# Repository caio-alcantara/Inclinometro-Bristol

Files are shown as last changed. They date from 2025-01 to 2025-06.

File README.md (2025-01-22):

# Inclinometro-Bristol
Projeto de um inclinômetro desenvolvido para a Bristol. Um dispositivo capaz de medir a angulação de perfuratrizes e enviar esse dado via bluetooth para o operador da máquina.

Desenvolvedor: <a href="https://www.linkedin.com/in/caio-alcantara-santos/">Caio de Alcantara Santos</a>

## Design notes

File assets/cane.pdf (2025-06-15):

irei participar de uma competição que contará com empresas e alunos. Formei um grupo de 6 pessoas contando comigo. O intuito da competição é fomentar o desenvolvimento tecnológico no brasil a partir do desenvolvimento de uma bengala inteligente a ser utilizada por pessoas cegas ou com visão afetadas a fim de, por exemplo, detectar possíveis obstáculos na altura da cintura da pessoa.

Alguns detalhes:

Este Concurso tem por objetivo específico reconhecer e premiar protótipos de bengalas ou dispositivos a elas conectados, fisicamente ou virtualmente, utilizados por pessoas cegas ou com baixa visão, que permitam antecipar obstáculos estáticos acima da linha de cintura. Com base em requisitos específicos e detalhados, este Edital pretende resolver o seguinte desafio: “Como permitir que pessoas cegas ou com baixa visão, usuárias de bengala, possam
antecipar obstáculos estáticos acima de sua linha de cintura”. Portanto, este CONCURSO quer estimular o desenvolvimento de uma solução acessível
financeiramente, adequada às condições brasileiras e desenvolvida com o maior nível possível
de tecnologia nacional incorporada.
Na primeira premiação, o Concurso terá como objetivo premiar até 10 (dez) ideias que estejam, no mínimo, na fase de conceito e/ou ideação. Propostas em níveis de maturidade tecnológica superiores ao conceito também poderão participar, desde que não tenham sido comercializadas e/ou introduzidas no mercado.

Os primeiros entregáveis são:

8.8.1. 01 (um) arquivo, sem qualquer identificação de autoria, contendo documento com a descrição detalhada da solução, a maturidade tecnológica desta, os métodos, técnicas e ferramentas que serão empregados no desenvolvimento, os resultados esperados, as tecnologias utilizadas, os avanços frente a outras iniciativas passadas e todas as informações
que o Proponente julgue relevante para permitir a avaliação dos critérios obrigatórios e classificatórios pela Comissão Especial de Avaliação.
8.8.1.1. Além destes elementos o documento deve conter imagens, esquemas e/ou ilustrações
estáticas que representem a configuração potencial da solução ou a própria solução, bem como
seu mecanismo e lógica de funcionamento.
8.8.1.2. As imagens, esquemas e/ou ilustrações estáticas deverão conter legendas que permitam adequada descrição dos objetos, bem como de seu mecanismo e lógica de funcionamento, de modo a possibilitar que o arquivo seja acessível a pessoas cegas ou com
baixa visão.
8.8.2. 01 (um) arquivo, sem qualquer identificação de autoria, referente ao Plano de Trabalho,
incluindo cronograma com vistas a avançar na maturidade tecnológica da solução, destacando os avanços planejados frente a proposta entregue, de forma a permitir que a solução possa ser
testada no Dia do Desafio segundo critérios estabelecidos neste Edital.
8.8.3. Os dois arquivos enviados, sem qualquer identificação de autoria, só serão aceitos na extensão PDF, com tamanho de até 50Mb marcados e estruturados, que permitam a leitura por
leitores de tela, com padrão PDF/UA (Universal Accessibility), garantindo que o PDF seja acessível.

Dessa forma, estou num processo, ainda individual, de brainstorming de ideias que possam ser fortes concorrentes a vencer este desafio. Sua tarefa aqui é:
1. Citar 10 ideias que possam ser utilizadas para a competição, e, no final, sintetizar quais são as 3 melhores. Você pode escolher 3 melhores ou mesclar ideias
2. Fazer uma procura profunda pela internet a fim de encontrar qualquer literatura que julgue útil no desenvolvimento de bengalas inteligentes e que também sirva para explicar, basear e citar fontes quando falando do problema em questão (pessoas cegas esbarrando em obstaculos, etc)

Para qualquer dúvida que restar, pergunte-me antes de iniciar a pesquisa profunda

O ChatGPT disse:
Antes de iniciar a pesquisa profunda, você poderia compartilhar alguns pontos para orientar melhor as ideias e buscas?

Algum limite de orçamento estimado por protótipo?

Vocês têm alguma preferência tecnológica (ex: sensores ultrassônicos, visão computacional, etc)?

Há alguma região geográfica do Brasil como foco (ex: clima, relevo, área urbana)?

Já há alguma ideia prévia ou esboço em mente por você ou seu grupo?

Vocês têm acesso a laboratórios, equipamentos específicos ou parcerias que possamos considerar nas ideias?

Com isso, poderei sugerir ideias mais realistas e fazer uma busca técnica mais eficaz.

Você disse:
1. Para a parte de ideação, não será necessário orçamento. Caso a nossa ideia seja selecionada, receberemos 90.000 reais para prosseguir com o desenvolvimento. Esse dinheiro estará dividido em salário para desenvolvedores e materiais para o prototipo. Ainda não está definido qual será o salario dos desenvolvedores
2. A preferencia está em sensores que possam ser embarcados em uma bengala. Dessa forma, pense em sensores pequenos, microcontroladores também pequenos que possam ser utilizados acoplados em uma bengala sem interferir no seu funcionamento básico. Além disso, considere que será desenvolvida uma placa de circuito industrial para o projeto
3. Não existe região focal porém tudo estará sendo desenvolvido em SP-SP
4. Não existe ideia prévia
5. Possuimos acesso a um laboratório maker que conta com impressoras 3d, maquinas de corte a laser e prototipadora de placa de circuitos bem como instrumental para solda e fabricação. Além disso, este laboratório conta com alguns componentes eletrônicos básicos que podemos utilizar. Componentes mais específicos terão que ser comprados a parte

O ChatGPT disse:
Ótimo! Vou reunir 10 ideias viáveis de bengalas inteligentes com foco em sensores embarcados, microcontroladores compactos e viabilidade de fabricação nacional em laboratório maker. Em seguida, vou sintetizar as 3 ideias mais promissoras e também fazer uma busca aprofundada por literatura técnica e científica que sirva como base para descrever o problema e justificar sua solução no documento da competição.

Volto em breve com os resultados.

Research completed in 8m· 33 fontes· 37 buscas
Ideias de Bengala Inteligente e Referências Técnicas para Competição Tecnológica

10 ideias de bengala inteligente para detectar obstáculos acima da cintura

A figura acima ilustra a estrutura básica de uma bengala inteligente: módulo de aquisição de dados (sensores), módulo de controle (microcontrolador), e módulo de feedback (vibração, som, etc.)
pmc.ncbi.nlm.nih.gov
wired.me
. Em contraste com a bengala tradicional, que só detecta obstáculos no chão, a bengala inteligente estende o alcance sensorial para a região acima da cintura, alertando o usuário sobre sinalização suspensa, galhos, braços de pessoas e outros obstáculos que a bengala comum ignora
pubmed.ncbi.nlm.nih.gov
tr.soe.ucsc.edu
. A seguir apresentamos dez ideias de design usando sensores e eletrônica acessível, sem interferir no uso básico da bengala:
Cabo com sensor ultrassônico frontal e suporte vibratório no punho: Um módulo ultrassônico compacto (por exemplo, HC-SR04 ou similares) fixado no topo do cabo da bengala, voltado para frente e ligeiramente para cima, mede distância de obstáculos à altura do peito e cabeça. Ao detectar objeto a menos de 1–2 m, um microcontrolador (STM32/Arduino Nano) aciona vibração no punho (motor tátil) para alertar o usuário. Esse sistema simples e barato usa peças comuns e pode ser prototipado em PCB caseiro. Não altera o uso do cabo – pode ser fixado como um acessório junto ao punho – e fornece aviso antecipado de obstáculos elevados, conforme em projetos similares
engineering.tamu.edu
wired.me
Dois sensores ultrassônicos cruzados no punho: Versão aprimorada com dois sensores ultrassônicos montados no punho, um apontando ligeiramente para frente (nível do peito) e outro mais inclinado para cima (nível da cabeça). Um único microcontrolador lê ambos e diferencia obstáculos baixos e altos. Esse arranjo duplica o campo coberto e melhora acurácia. O feedback pode combinar vibração e alertas sonoros simples. A estratégia de dois ultrassons foi estudada em literatura recente, cobrindo obstáculos em solo e suspensos mdpi.com
. Os componentes são econômicos e facilmente acoplados ao cabo, sem atrapalhar a bengala normal.
Sensor de distância a laser (LiDAR) 2D giratório no cabo: Um pequeno módulo LiDAR time-of-flight (por exemplo, LIDAR-Lite ou RPLIDAR) montado no cabo em nível de peito, cobrindo 360° (giro do módulo) ou 180° à frente. Esse sensor mapeia obstáculos em tempo real em torno do usuário. Ele exige mais poder computacional (p. ex. Raspberry Pi ou STM32 com driver) e um motor giratório (protótipo em 3D fácil), mas fornece detecção precisa de obstáculos estáticos e móveis acima da cintura. Sistemas complexos usando LiDAR 2D e câmera RGB-D foram demonstrados em pesquisas
mdpi.com
. Em uma versão maker, pode-se usar um LiDAR de pulso ou varredura mecânica controlada por PCB próprio, viabilizando mapeamento básico e alerta de colisão sem alterar a bengala.
Câmera de profundidade compacta com visão computacional: Instalar uma câmera de profundidade leve (como Intel RealSense ou módulo ToF) no topo da bengala, conectada a um microcomputador pequeno (Raspberry Pi Zero ou similar). O sistema executa um algoritmo simples de detecção de objetos (por exemplo, distância fixa ou uma rede neural leve) e avisa sobre obstáculos altos via áudio ou vibração. Embora mais complexo, esse arranjo é viável em laboratório maker (placa customizada + gabinete impresso) e usaria componentes disponíveis (câmera comum ou módulo ToF). Dispositivos avançados de visão são caros, mas modelos mais simples podem ser obtidos nacionalmente ou sob orçamento futuro. A câmera permite identificar diferentes tipos de obstáculos (placas, pessoas), indo além do alcance dos ultrassons.
Sensor infravermelho (ToF) direcional no punho: Utilizar sensores infravermelhos time-of-flight (por exemplo, VL53L1X) montados no punho, que emitem raios infravermelhos invisíveis e medem a distância de objetos refletores. Um ou mais sensores ToF podem cobrir áreas frontais e superiores com alcance de até vários metros. Essa tecnologia é pequena, de baixo custo e já usada em projetos de assistente para cegos. Com microcontrolador dedicado, o sistema gera aviso vibratório quando detecta obstáculo dentro de determinado raio. O sensor ToF é de fácil integração em PCB customizado e não sofre com condições de baixa luminosidade.
Radar milimétrico ou sensor ultrassônico “tipo adas” no topo: Aproveitando módulos de radar mmWave (baseados em chips TI IWR ou similar) ou sensores ultrassônicos modulares, este conceito instala um pequeno transceptor na ponta da bengala (ou no cabide superior), apontando para frente/ cima. O radar detecta objetos sólidos (pessoas, postes, paredes) acima da altura da bengala, superando limitações do ultrassom em superfícies absorventes. Embora mais sofisticado e caro, existem kits de radar disponíveis que poderiam ser adaptados e integrados em um projeto nacional futuro. O uso de radar permitiria detecção mesmo através de poeira/fumaça e sem necessidade de iluminação. Cintos ou alça vestível sincronizados com a bengala: Uma abordagem híbrida: um dispositivo vestível (como um colar ou faixa de peito) equipado com sensores ultrassônicos/câmeras na altura dos ombros, emparelhado via Bluetooth com a bengala. Quando o sensor vestível identifica obstáculo acima da cintura, ele envia alerta para a bengala (microcontrolador) que vibra no punho. Assim, os sensores não ficam presos ao cabo, evitando sobrecarga. Esse conceito mantém a bengala leve e permite montagem de sensores maiores. A comunicação sem fio pode usar módulos BLE baratos. Em laboratório maker seria possível produzir a alça e a placa de circuito vestível com os recursos disponíveis.
Módulo de câmeras infravermelhas estereoscópicas: Usar duas pequenas câmeras infravermelhas montadas no punho (formando estéreo), combinadas a um microcontrolador com processamento de profundidade simples. Isso criaria um “visão de profundidade” sem laser. Com algoritmos de estereoscopia básica rodando em microcontrolador potente (ou em smartphone via app), seria possível estimar distância de obstáculos suspensos. Essa solução é mais complexa de implementar, mas utilizaria componentes disponíveis (câmeras menores) e processamento personalizado. A ideia é similar a sensores de visão noturna adaptados para mapeamento de obstáculos.
Sensor de ultrassom de varredura horizontal (fenda linear): Em vez de um único sensor, colocar uma matriz linear de pequenos sensores ultrassônicos ou infravermelhos ao longo de uma barra no topo da bengala. Ao girar ou oscilar a bengala, a matriz faz uma varredura horizontal ampla. Os sinais combinados são processados para indicar a direção do obstáculo. Esse design mantém a forma tradicional da bengala (uma barra superior) mas com vários emissores, cobrindo um campo maior sem precisar de motor. Projetar a barra e a placa de circuito seria possível com impressão 3D e soldagem manual.
Integração com smartphone e aplicativos de visão computacional: Embora não seja um hardware exclusivo da bengala, esta ideia usa a câmera de um smartphone fixado ao cabo e software dedicado de computador de bordo. O smartphone (posicionado na bengala) roda um app de detecção de obstáculos (visão por AI) e envia avisos para um vibrador no punho via Bluetooth. Em laboratório maker seria fácil prototipar a montagem da dobradiça do celular e desenvolver app básico. Isso permite usar técnicas avançadas (reconhecimento de placas, semáforos etc.), embora dependa de software móvel. A vantagem é aproveitar componentes comuns (celular) e customizar o sensor virtualmente.
Seleção das 3 melhores ideias
Das dez ideias acima, as três soluções mais promissoras (ou combinações delas) são: Ultrassom duplo no punho + feedback tátil: Combina as ideias 1 e 2. Um módulo ultrassônico duplo no cabo (um sensor para obstáculos baixos, outro para altos) é simples, barato e já testado em estudos prévios
mdpi.com
engineering.tamu.edu
. Essa configuração fornece detecção eficiente em múltiplas alturas, com um único microcontrolador STM32/Arduino. O alerta tátil (vibração) não atrapalha a bengala normal. Pode ser prototipado facilmente com PCB caseiro e impressão 3D para suporte. A viabilidade é alta, pois usa componentes disponíveis no país (HC-SR04, Motores vibratórios, MCU comum) e pode ser industrializado a baixo custo. Além disso, pode-se integrar módulo Bluetooth opcional para expansão futura (por ex. combinar com smartphone, fusão com GPS).
LiDAR 2D compacto montado no cabo: Uma bengala equipada com um mini-LiDAR time-of-flight (como o módulo TFMini o semelhante) que varre lateralmente ou gira (versão giratória) pode mapear obstáculos no entorno imediato em qualquer altura. Essa ideia (inspirada na pesquisa de Mai et al.
mdpi.com
) proporciona detecção mais precisa que ultrassom, cobrindo diversos tipos de objetos estáticos acima da cintura. Embora mais sofisticado (requer MCU capaz de processar pontos LiDAR, talvez Raspberry Pi Zero ou STM32 avançado), ainda é factível num laboratório maker, usando placa customizada e estrutura impressa para o mecanismo de varredura. Em longo prazo, após prova de conceito, o LiDAR garante acesso a soluções de navegação avançada (como SLAM), ainda que o foco inicial seja só detecção de obstáculos.
Combinação de ultrassom e câmera ToF (sensor infravermelho): Unir o ultrassom para detecção simples com um sensor ToF infravermelho de longo alcance (por ex. VL53L1X) num único módulo de controle. O ultrassom alerta obstáculos a curta distância (até ~3 m) com alta confiabilidade, enquanto o sensor ToF atua em média distância até ~4–8 m. Essa fusão aumenta alcance sem muito custo adicional. O feedback poderia ser tanto vibratório quanto sonoro (alto-falante miniatura), conforme preferência do usuário. A vantagem dessa “solução mista” é usar componentes muito disponíveis no mercado local (sensores ultrassônicos e ToF) e controladores acessíveis (ESP32 ou Arduino Nano), além de ser facilmente montada em uma PCB única. Em ambiente maker, a fusão permite otimizar blindagem a ruídos (ultrassom ao ar livre e luz solar, por exemplo) e aumentar a confiabilidade geral.
Essas três ideias foram escolhidas por oferecerem maior equilíbrio entre viabilidade técnica e benefício prático. Todas respeitam o uso tradicional da bengala (fixam-se no cabo ou punho, sem alterar o design básico) e podem ser prototipadas com tecnologia acessível: microcontroladores pequenos (STM32, Arduino, ESP32), sensores ultrassônicos/ToF comuns e montagem em PCB artesanal. Além disso, podem se beneficiar de fabricação local (impressão 3D da carcaça, corte a laser, montagem eletrônica) e posterior escala industrial nacional.
Fundamentação teórica e referências
A necessidade de detectar obstáculos acima da cintura está bem documentada. Pesquisas mostram que bengalas comuns não atingem esses obstáculos, expondo cegos a riscos elevados. Por exemplo, Cheng (2016) observa que “bengalas brancas e andadores não detectam obstáculos na via nem objetos acima da cintura”
pubmed.ncbi.nlm.nih.gov
. Em relatório sobre acidentes de mobilidade, verificou-se que apenas 2% dos cegos nunca sofreram colisões na altura da cabeça, e que 23% desses acidentes tiveram consequências médicas, com 60% dos casos exigindo atendimento hospitalar
tr.soe.ucsc.edu
. Ou seja, quase um em cada quatro impactos de altura resultou em ferimentos sérios tr.soe.ucsc.edu
. Esses dados ressaltam a importância de tecnologias assistivas que preencham essa lacuna de sensoriamento. Há diversas soluções tecnológicas em desenvolvimento ou comercialização. Dispositivos como o WeWALK Smart Cane (imagem abaixo) já usam sensores ultrassônicos voltados para frente para detectar obstáculos acima do peito, fornecendo resposta háptica (vibração) ao usuário
wired.me
. Em reportagem, constatou-se que “a bengala tradicional não detecta nada acima da cintura” e que pessoas cegas facilmente esbarram em placas e caixas elétricas suspensas wired.me
. Times de engenharia universitária (como a TAMU) criaram protótipos como o NOVA, acessório de bengala com sensor ultrassônico e vibrações para alertar obstáculos acima da cintura
engineering.tamu.edu
. Na literatura acadêmica, há projetos de bengalas com ultrassom duplo – um para obstáculos no solo e outro para obstáculos altos – que alertam o usuário por vibratórios e sinais sonoros
mdpi.com

A imagem acima mostra a bengala WeWALK comercial, ilustrando um design real de bengala inteligente: ela incorpora um sensor ultrassônico e alto-falante no punho, conectados a um aplicativo de smartphone
wired.me
. Esse tipo de solução confirma que abordagens ultrassônicas com microcontroladores e feedback háptico são práticas e eficazes no mundo real. Em outro extremo, pesquisas como de Mai et al. exploram sensores avançados: eles propõem uma bengala equipada com LiDAR 2D e câmera RGB-D, usando um Jetson Nano para realizar SLAM e reconhecimento de obstáculos
mdpi.com
. Embora esse arranjo seja mais complexo, ele demonstra o potencial de fusão de sensores (laser + visão) para navegação inteligente. Revisões recentes destacam que smart canes podem integrar uma vasta gama de sensores – ultrassom, infravermelho, LIDAR, câmera, radar – acoplados a microcontroladores como STM32 ou Raspberry Pi pmc.ncbi.nlm.nih.gov
. Em resumo, a bibliografia indica claramente o problema de obstáculos acima da cintura e valida soluções tecnológicas semelhantes às propostas aqui. Nossos conceitos aproveitam os achados desses estudos: ultrassom para alcance curto/médio
mdpi.com
engineering.tamu.edu
; sensores de profundidade (ToF ou LiDAR) para distâncias maiores; microcontroladores compactos e barateados; além do uso de feedback háptico e sonoro já consagrados. Dessa forma, as referências encontradas sustentam a justificativa do projeto, mostrando que nossa proposta é tecnicamente viável e socialmente relevante. Elas fornecem os dados estatísticos sobre acidentes
tr.soe.ucsc.edu
e exemplos de implementações atuais
wired.me
mdpi.com
que fundamentam a ideia de aprimorar a bengala branca tradicional. Referências principais: Artigos e relatórios revisados incluem a pesquisa de Cheng (2016) sobre dispositivo cap-connected

pubmed.ncbi.nlm.nih.gov
, o caso WeWALK relatado na mídia wired.me
wired.me
, o projeto TAMU NOVA
engineering.tamu.edu
, e estudos de revisão e implementação de smart canes com ultrassom e LiDAR mdpi.com
mdpi.com
pmc.ncbi.nlm.nih.gov
. Esses materiais fornecem estatísticas, dados de eficácia e descrições de arquiteturas de sensores que servem como base para o nosso projeto.

Fontes

Você disse:
Não sei se estou maluco, mas as pessoas não usam as bengalas segurando elas aproximadamente na linha da cintura? Como sensores no cabo da bengala, por exemplo, poderiam detectar objetos na altura de peito ou de cabeça?

O ChatGPT disse:

Pensou por 7 segundos
Resumo das descobertas
Embora a bengala seja segurada na altura da cintura (ou esterno), é perfeitamente viável instalar sensores nesse ponto de apoio para “olhar” para frente e para cima, cobrindo a região do peito e da cabeça. A chave está no ângulo de montagem e na posição elevada do sensor no punho/parte superior da bengala, de modo que o feixe ultrassônico, infravermelho ou laser seja direcionado para frente e para cima, interceptando obstáculos suspensos. Estudos de design e manuais de produtos comprovam que esse posicionamento não interfere no uso tradicional da bengala e garante detecção antecipada de objetos acima da cintura.
1. Altura de uso da bengala
Comprimento típico: a bengala longa costuma chegar do chão até o esterno ou mesmo queixo do usuário, dependendo da preferência e altura da pessoa
Leader Dogs for the Blind

Posição de empunhadura: ao andar, o usuário segura a bengala verticalmente junto ao corpo, com o punho aproximadamente na altura da cintura ou do esterno (peito)
World Health Organization (WHO)

Variações: alguns preferem bengalas um pouco mais longas, chegando ao queixo, para maior alcance no solo e garantia de deteção de desníveis
BAWA Tech
2. Como sensores no punho detectam obstáculos acima da cintura
2.1 Ângulo de montagem dos sensores
Sensores inclinados para cima: basta montar o sensor (ultrassom, ToF ou LiDAR) no punho/parte superior, mas com ângulo de inclinação de cerca de 15°–30° em relação à vertical, de forma a abranger do nível da cintura até a altura da cabeça
support.wewalk.io

Campo de visão ajustado: sensores como o VL53L1X (ToF) têm campo de cobertura de até 45°; orientá‑lo para cima amplia a zona detectada acima da linha da cintura
sensortips.com

2.2 Exemplos práticos em smart canes
WeWALK Smart Cane: o sensor de obstáculos está localizado acima da lanterna, no ponto mais alto do cabo, apontando ligeiramente para cima para cobrir do tórax à cabeça support.wewalk.io

BAWA Cane: usa um sensor ultrassônico posicionado próximo ao punho, com cobertura angular de 45°, detectando obstáculos até 1,2 m acima da cintura
sensortips.com

Design acadêmico (Nada et al., 2015): um ultrassom na base detecta solo; outro junto ao cabo, inclinado para cima, detecta obstáculos na altura da cabeça sem “ver” a própria bengala
PMC
3. Evidências em literatura técnica
Estudo / FontePositionamento do sensor | Ângulo / Alcance | Feedback / Notas
WeWALK User’s Manual | Acima da lanterna, no punho Detecta do tórax ao nível da
cabeçaVibração e áudio
support.wewalk.io
BAWA Cane (SensorTips) Perto do punho, campo 45° Até 1,2 m acima da cintura Resolução ±1 cm, 4,5 m alcance

sensortips.com
Nada et al. (2015) | Sensor embaixo + sensor no punho inclinado | Solo + cabeça
Evita autointerferência, sem movimento de varredura
PMC
Kanagaratnam (2009)Ultrassom/laser/IR no punho Acima do joelho e até peito Guideline de design de smart cane
Revista Internacional de Design
ResearchGate “Smart cane with range notification” Sensor junto ao cabo, posicionado para não “ver” caneDa cintura ao chão Prototype description
ResearchGate
4. Por que não “enxergar” a bengala
Blindagem física: o suporte e carcaça impressos em 3D protegem o sensor de refletir no próprio corpo da bengala.

Ângulo crítico: ao inclinar o sensor para cima, o feixe não incide na parte interna da bengala, mas sim no espaço livre à frente do usuário
Science Buddies

Configuração dual‑sensor: usar dois sensores (um baixo, outro alto) evita pontos cegos e garante cobertura completa sem autointerferência
MDPI
5. Conclusão
Mesmo segurando a bengala na cintura, basta posicionar e inclinar adequadamente os sensores no punho ou na parte superior do cabo para que o feixe (ultrassônico, infravermelho ou laser) aponte para frente e para cima, detectando com segurança qualquer obstáculo na região do peito e da cabeça antes que o usuário colida. A abordagem é amplamente validada por produtos comerciais (WeWALK, BAWA) e por pesquisas acadêmicas (Nada et al., Kanagaratnam), mostrando que:

Ângulo de montagem garante cobertura de altura extra.

Blindagem e design de carcaça evitam que o sensor “veja” a bengala.

Combinação de sensores (baixo + alto) maximiza a área monitorada.

Assim, a ideia de sensores no cabo é totalmente compatível com o uso tradicional da bengala, acrescentando deteção de obstáculos acima da cintura sem comprometer a mobilidade ou ergonomia do usuário.

Fontes

Você disse:
considerando uma solução industrial e comercializável, qual sensor ultrassonico você usaria?
O ChatGPT disse:

Pensou por 34 segundos
Resumo da recomendação
Para um produto industrial e comercializável, recomendamos o sensor ultrassônico Pepperl+Fuchs UC18GS (por exemplo, modelo UC500‑18GS‑2EP‑IO‑V15), pelas seguintes razões principais: corpo em aço inoxidável M18 compacto e robusto (IP67), interface de comunicação avançada (IO‑Link/IrDA), campo de medição ajustável (30 … 500 mm ou até 1 000 mm), alta imunidade a interferências e facilidade de parametrização em linha de produção. Esse sensor alia confiabilidade industrial, tamanho reduzido adequado para montagem no punho de uma bengala e recursos de configuração que viabilizam produção em série e certificação de segurança.
1. Critérios para seleção de sensor ultrassônico industrial
CritérioJustificativa
Dimensões compactas Deve caber no punho ou parte superior da bengala sem interferir na ergonomia.
Proteção ambiental Grau de proteção mínimo IP67 para resistir a chuva, poeira e limpeza frequente.
Faixa de medição Alcance de pelo menos 0,03 m a 0,5 m (obstáculos próximos) e idealmente até 1 m (cabeça e tronco).
Angulo de feixe ajustável Permite direcionar o cone de som para cobrir somente a região à frente e acima da cintura, evitando auto‑eco na bengala.
Tempo de resposta < 20 ms para alerta em tempo real sem latência perceptível. Interface e parametrização IO‑Link ou IrDA para configuração rápida em linha de montagem e diagnóstico remoto.
Robustez e certificações Construção metálica, blindagem EMC, compensação de temperatura interna, confiabilidade em larga escala.
Tensão de alimentação Compatível com 5 V ou 12–30 V DC, adaptável a microcontroladores embarcados (ESP32, STM32).
SaídasAnalógica (0–10 V ou 4–20 mA) e/ou digital (PNP/NPN, push‑pull), para integração simples com MCU.
2. Sensor recomendado: Pepperl+Fuchs UC18GS
2.1 Especificações principais
Modelo exemplo: UC500‑18GS‑2EP‑IO‑V15

Faixa de medição: 30 … 500 mm (outro variante até 1 000 mm) satis.tiootomasyon.com

Dead band: 30 mm (500 mm range) / 70 mm (1 000 mm range) satis.tiootomasyon.com

Conector: M12 × 1.5, pinagem 4‑pinos satis.tiootomasyon.com

Proteção: IP67, metal housing M18 satis.tiootomasyon.com

Temperatura: –25 … +70 °C
satis.tiootomasyon.com

Interface: IO‑Link 1.1 + IrDA (infravermelho) para parametrização sem contato satis.tiootomasyon.com

Saídas: 2× push‑pull ou 1× push‑pull + 1× analógica (4–20 mA/0–10 V) satis.tiootomasyon.com

Ajustes on‑sensor: botões para configuração de feixe, supressão de alvos, sincronização automática
satis.tiootomasyon.com

2.2 Vantagens para bengala inteligente
Compactação extrema: diâmetro M18 (18 mm) permite alojar o sensor num suporte impresso 3D junto ao punho, sem aumentar muito o volume
pepperl-fuchs.com

Feixe configurável: ajuste de ângulo para não “enxergar” a própria bengala e focar em obstáculos de 0,5 m a 1 m à frente, na altura do tórax e cabeça
satis.tiootomasyon.com

Robustez industrial: carcaça em aço inox, proteção IP67 e compensação de temperatura garantem funcionamento estável em ambientes externos (chuva, poeira) rusautomation.ru

Parametrização em massa: IO‑Link facilita ajustes e calibração em linha de produção, essencial para escala comercial
satis.tiootomasyon.com

Baixa latência: tempo de resposta < 15 ms, adequado para alerta háptico instantâneo sem atrasos perceptíveis

Banner Engineering
3. Comparação com outras opções industriais
SensorFaixa (mm) | Tamanho/shape | IP | Interface | Citação
Pepperl+Fuchs UC18GS | 30 – 500 / 70 – 1000 M18 cilindro IP67 IO‑Link, IrDA
satis.tiootomasyon.com
Banner Engineering QS18U Series 50 – 500 Barrel (φ18 × 50 mm) IP67 Analógica/Digital
Banner Engineering
MaxBotix HRLV-MaxSonar-EZ | 50 – 500 | PCB board (76 × 19 mm) | IP64
Analógico, PW
maxbotix.com
Murata MA40S4S | 200 – 4000 | Disco φ10 mm IP40 Analog
murata.com
Pepperl+Fuchs USi-industry 50 – 3000 M30 housing IP69K CAN, analog pepperl-fuchs.com

Banner QS18U: boa resposta (15 ms) mas range limitado a 500 mm e sem IO‑Link; ideal para protótipos, menos flexível em produção
Banner Engineering

MaxBotix: barato e preciso, mas não tem proteção IP67 completa e carece de interface digital configurável em produção
maxbotix.com

Murata MA40S4S: compacto, mas range demasiado longo e sem encapsulamento robusto para uso externo
murata.com
4. Conclusão
O Pepperl+Fuchs UC18GS equilibra tamanho, robustez, precisão e facilidade de configuração em larga escala, atendendo aos requisitos de um produto comercial de massa. Sua construção M18 IP67, feixe ajustável, comunicação IO‑Link e rápida resposta garantem segurança e confiabilidade para usuários de bengalas inteligentes, enquanto viabilizam um processo industrial de fabricação e calibração eficiente.

Fontes

Você disse:
dê exemplos de sensores que ainda sejam viaveis para o projeto industrial mas que sejam mais fáceis de serem encontrados

O ChatGPT disse:

Pensou por 9 segundos
Principais opções de sensores ultrassônicos fáceis de encontrar para produção industrial Para um produto comercializável, além de modelos de alta gama como o Pepperl+Fuchs UC18GS, existem diversos sensores ultrassônicos industrial‑grade, com bom equilíbrio entre disponibilidade, preço e robustez, que podem ser adquiridos junto a distribuidores nacionais e integrados a uma bengala inteligente. A seguir, seis exemplos de sensores compactos, protegidos contra poeira e água, com faixas de medição adequadas (0,05–1 m) e interfaces simples (saída digital ou analógica):
SensorFaixa (mm) | Housing | IP | Saída Interface | Comentário
Banner QS18U (QS18UPAQ8) | 50–500 | M18 cilindro IP67 PNP push‑pull
M12 4‑pinos Miniatura; teach‑mode on‑sensor
Banner Engineering
MaxBotix HRLV‑MaxSonar‑EZ1 (MB1013) 300–5000 | PCB board | IP64 Analógico,
PWM, UART Cabo 4‑fio | Alta resolução 1 mm; auto‑calibração
Maxbotix
Maxbotix
Turck QT50ULB | 200–8000 | Barrel φ50 mm | IP67 Analógico (0–10 V)
DIP‑switch config | Campo longo; compensação temp.
Turck
SICK UM12 40–1200 | M12 housing IP67 Analógico, digital | M12 4‑pinos
M12 compacto; fácil integração
SICK
Keyence FW‑Series 50–1000 (var.)M18×63 mm IP67 Digital, analog Cabo integral Alta potência; resistente a poeira
Keyence
Murata MA40S4S | 200–4000 | Disco φ10 mm IP40 Analógico | PCB mounting
Muito compacto; para integração dens
1. Banner QS18U (QS18UPAQ8)
Faixa: 50–500 mm

Housing: M18 cilindro, aço inox; IP67
Banner Engineering

Saída: PNP push‑pull; two‑wire teach‑mode programável sem ferramentas

Banner Engineering

Por que escolher: ultra‑compacto, disponível em distribuidoras locais (Mouser, Farnell), fácil parametrização on‑sensor, ideal para montagem em punho de bengala.

2. MaxBotix HRLV‑MaxSonar‑EZ1 (MB1013)
Faixa: 300–5000 mm, resolução 1 mm
Maxbotix
Maxbotix

Housing: PCB exposto; IP64

Saída: Analógico (0–5 V), PWM, UART serial

Por que escolher: muito popular em prototipagem e produção leve, suporte global, documentação extensa, auto‑calibração de temperatura, ótimo custo-benefício.

3. Turck QT50ULB
Faixa: 200–8000 mm; blind zone 200 mm
Turck

Housing: Barrel φ50 mm; IP67, robusto para ambientes externos

Saída: Analógico (0–10 V) ou corrente (4–20 mA) configurável por DIP‑switch

Por que escolher: faixa estendida, fácil ajuste de saída, muito usado em linhas de produção nacionais.

4. SICK UM12
Faixa: 40–1200 mm
SICK

Housing: M12 rosca, metal; IP67

Saída: Analógico (0–10 V) e digital (push‑pull)

Por que escolher: padrão M12 facilita troca e manutenção, ampla rede de distribuição, excelente suporte técnico.

5. Keyence FW‑Series
Faixa: 50–1000 mm (variações de modelo)
Keyence

Housing: M18 × 63 mm; IP67

Saída: Digital NPN/PNP, opcional analógica

Por que escolher: alto desempenho em ambientes com poeira e sujeira, reconhecido pela estabilidade de detecção.

6. Murata MA40S4S
Faixa: 200–4000 mm

Housing: disco φ10 mm; IP40

Saída: Analógico

Por que escolher: tamanho mínimo para projetos ultracompactos, ideal para integração interna em PCB customizado.

Considerações para integração
Proteção e carcaça

Sensores industriais (QS18U, SICK UM12, Keyence FW) já vêm com IP67; use suportes impressos em 3D para fixação no punho.

Interferência e blindagem

Ajuste o ângulo de feixe para não “enxergar” a bengala (use suporte inclinado ~15°).

Alimentação e interface

A maioria opera em 12–30 V DC (industriais) ou 5 V DC (protótipos); adapte com reguladores simples.

Parametrização em série

Opções com IO‑Link (Banner QS18U) ou teach‑mode on‑sensor agilizam calibração em produção.

Essas opções são mais acessíveis em distribuidores brasileiros (Mouser, Farnell, RS Brasil) e satisfazem requisitos de robustez, tamanho e faixa de medição para uma bengala inteligente industrial, permitindo escalar o protótipo para produção comercial.

Fontes

Você disse:
Considerando tudo o que foi dito aqui, qual seria uma possível solução inovadora e diferente do tradicional que já é tentado?

O ChatGPT disse:
Considerando as limitações das bengalas inteligentes tradicionais — como a dificuldade em detectar obstáculos acima da cintura e a complexidade de uso —, uma solução inovadora e diferenciada poderia ser o desenvolvimento de um sistema modular de detecção e feedback multissensorial, inspirado no conceito de "bigodes virtuais" .

🌐 Proposta: Sistema Modular de Detecção e Feedback Multissensorial
1. Módulo de Detecção de Obstáculos Elevados
Incorporação de sensores ultrassônicos compactos e de baixo custo, como o HC-SR04, posicionados estrategicamente no punho da bengala para detectar obstáculos na altura do tronco e da cabeça. Esses sensores podem ser configurados para identificar objetos em diferentes faixas de distância, alertando o usuário sobre possíveis colisões.
Solve for Tomorrow LATAM
2. Feedback Multissensorial
Utilização de atuadores vibratórios reciclados de dispositivos móveis, distribuídos ao longo do punho da bengala, para fornecer feedback tátil direcional ao usuário. Esse sistema permitiria que o usuário percebesse a direção e a proximidade dos obstáculos, melhorando a navegação em ambientes complexos.
3. Integração com Tecnologias de Cidades Inteligentes
Incorporação de módulos de comunicação, como o LoRaWAN, para permitir que a bengala se conecte a infraestruturas de cidades inteligentes. Isso possibilitaria funcionalidades adicionais, como localização em tempo real, alertas de tráfego e informações sobre o ambiente urbano.
4. Design Modular e Personalizável
Desenvolvimento de um sistema modular que permita a personalização da bengala de acordo com as necessidades específicas de cada usuário. Isso incluiria a possibilidade de adicionar ou remover módulos de detecção, feedback e comunicação, adaptando a bengala para diferentes ambientes e preferências pessoais.
repositorio.umc.br

🔍 Benefícios da Solução Proposta
Detecção Abrangente de Obstáculos: Capacidade de identificar obstáculos em diferentes alturas, incluindo aqueles acima da cintura, que são frequentemente negligenciados por bengalas tradicionais.
fatecpp.edu.br

Feedback Intuitivo e Direcional: Sistema de feedback tátil que fornece informações claras e diretas sobre a localização dos obstáculos, facilitando a tomada de decisões rápidas pelo usuário.

Conectividade com Ambientes Inteligentes: Integração com tecnologias de cidades inteligentes para fornecer informações contextuais adicionais, aumentando a segurança e a autonomia do usuário.

Personalização e Escalabilidade: Design modular que permite a adaptação da bengala às necessidades individuais dos usuários, bem como a fácil atualização ou substituição de componentes.

️ Viabilidade de Desenvolvimento
Com acesso a um laboratório maker equipado com impressoras 3D, máquinas de corte a laser e prototipadoras de placas de circuito, é possível desenvolver e testar os módulos propostos. A utilização de componentes eletrônicos básicos disponíveis no laboratório, combinada com a aquisição de sensores específicos, permitirá a criação de protótipos funcionais para validação e refinamento da solução.

📚 Referências
"Haptics-based, higher-order Sensory Substitution designed for Object Negotiation in Blindness and Low Vision: Virtual Whiskers"
arXiv

"LoRaWAN"
Revista FT
+2
Wikipédia, a enciclopédia livre +2
Wikipédia, a enciclopédia livre
+2

"Bengala eletrônica de baixo custo se comunica com tecnologias de smart cities" tga.ifmt.edu.br
+3
dci.unifesp.br
+3
Solve for Tomorrow LATAM
+3

Essa abordagem inovadora visa superar as limitações das bengalas inteligentes tradicionais, oferecendo uma solução mais abrangente, personalizável e integrada ao ambiente urbano moderno.

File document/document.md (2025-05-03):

# Inclinômetro Bristol

## 1. Introdução à Bristol e ao problema

&emsp;"A Bristol é uma empresa genuinamente brasileira, que se destaca na fabricação de implementos agrícolas ligados ao ramo da motosserra e na fabricação de perfuratrizes e brocas, amplamente utilizados na construção civil. Sua linha de produtos é bastante extensa, suprindo as necessidades de uma enorme gama de consumidores no Brasil e exterior." 

&emsp;Dessa forma, a Bristol se coloca como uma empresa B2B que vende, para empresas do setor agrícola, construção civíl, etc, máquinas que dão suporte nessas determinadas áreas. Para este projeto, foi indicado um problema/necessidade: a falta de uma maneira simples e rápida para se medir a inclinação de uma máquina perfuratriz. Medir a inclinação de uma perfuratriz é algo útil por diversos motivos, incluindo:
* Precisão no Posicionamento: Em muitos projetos de perfuração, como na indústria de petróleo, gás ou mineração, é de extrema importância que a perfuração siga um ângulo exato para atingir um ponto ou camada específica do subsolo. Medir a inclinação ajuda a garantir que o furo esteja na direção correta.
* Segurança Operacional: Uma perfuração desalinhada pode resultar em falhas no equipamento, vazamentos ou até acidentes. Medir a inclinação permite monitorar a trajetória da perfuratriz e ajustar o ângulo conforme necessário para evitar problemas.
* Eficiência e Custo: A perfuração em ângulos inadequados pode levar a um maior consumo de recursos, como tempo e energia. Controlar a inclinação ajuda a otimizar o processo, tornando-o mais eficiente e econômico.
* Controle da Direção: Em algumas operações, como a perfuração direcional, é necessário controlar a trajetória para chegar a alvos específicos. Medir a inclinação é essencial para garantir que o furo siga o caminho desejado.

&emsp;Com todos esse becefícios expostos, fica claro que não possuir uma maneira simples, rápida e direta de medir essa inclinação logo pode se tornar uma dor e um ponto de gargalo para a produção. Assim, o presente projeto tem como objetivo solucionar este projeto, servindo como um analgésico para esta dor. 

## 2. Apresentação da solução

&emsp;De início, foi definido um escopo que conseguísse suprir todas as necessidades da Bristol. A solução deveria suprir a necessidade de medir a inclinação do maquinário enquanto opera em situações adversas, incluindo altos níveis de vibração, alta temperatura e presença de poeira e/ou água. A partir desses requisitos, a solução pensada envolve um dispositivo IOT (Internet das Coisas) que será acoplado em uma perfuratriz. O dispositivo deverá utilizar sensores para medir a inclinação da perfuratriz em relação ao solo e enviar esse dado via BLuetooth para o celular do operador, que deve poder se conectar ao dispositivo com o seu celular e visualizar os dados de maneira simples. Além disso, todo o case/carenagem do dispositivo deve ser desenvolvido tendo em mente as condições de alta presença de poeira, temperaturas altas (50°C) e autonomia de bateria de pelo menos 24 horas. Mais detalhes sobre os requisitos funcionais e não-funcionais podem ser encontrados na seção X.X.

### 2.1. Divisão de fases do projeto

&emsp;A principio, foi acordo com a Bristol que o projeto seria desenvolvido ao longo de 5 meses a fim de se entregar uma versão completa e pronto para uso. Além disso, foram definidos entregáveis para cada mês de execução do projeto, levando em consideração que o primeiro mês é voltado para compra e teste de componentes, bem como desenvolvimento preliminar de uma placa inicial para validação da ideia. As entregas são como seguem:

**Entregáveis**:
- Protótipo funcional em protoboard com ESP32 e MPU9250.
- Firmware básico para:
  1. Leitura dos dados do inclinômetro (ângulos em X e Y).
  2. Cálculo do ângulo de inclinação em relação ao solo.
  3. Transmissão dos dados via Bluetooth para um aplicativo simples (ex.: interface básica ou software como Serial Bluetooth Terminal).
- Projeto e fabricação de uma PCI inicial simples para substituir a protoboard, com:
     - Conexões para ESP32, acelerômetro e bateria.
- Teste do dispositivo em campo para verificar funcionamento básico.
- Documentação inicial sobre os componentes usados e instruções para testes.
- Case protótipo: Desenvolvimento inicial de um protótipo de case simples, a ser desenvolvido em máquina corte a laser ou impressora 3D (ainda não resistente a água/poeira).

#### 2º Mês - Protótipo Aprimorado
**Objetivo**: Aprimorar o protótipo básico, implementar funcionalidades extras e preparar o dispositivo para um ambiente mais robusto.

**Entregáveis**:
- Firmware aprimorado com:
  1. Indicação do nível da bateria.
  2. Armazenamento interno dos dados de inclinação (em caso de perda de conexão Bluetooth).
  3. Otimização do cálculo de inclinação.
- Melhorias na PCI: Projeto de uma segunda versão com:
  1. Layout otimizado para resistência a vibração.
  2. Melhor proteção contra ruídos e falhas.
  3. Inclusão de LED para status de ligação e conexão Bluetooth.
- Implementação de uma interface web simples para exibir dados de inclinação e nível da bateria (em desenvolvimento inicial).

#### 3º Mês - Protótipo Avançado
**Objetivo**: Desenvolver um protótipo mais próximo da versão final, com foco em funcionalidades de software e conectividade.

**Entregáveis**:
- Firmware avançado com:
  1. Atualização de firmware via web (OTA).
  2. Melhorias na estabilidade da conexão Bluetooth.
  3. Modos de operação otimizados para economia de energia.
- Interface web funcional:
  1. Dashboard simples para exibir inclinação em tempo real, histórico e nível da bateria. Incluindo uma versão a ser utilizada como app mobile.

#### 4º Mês - Versão Pré-Final
**Objetivo**: Refinar o hardware e software, incluindo integração de todas as funcionalidades. Aprimorar case.

**Entregáveis**:
- Placa de circuito avançada: Projeto finalizado para uma versão industrial robusta, incluindo a utilização de CI's ao invés de módulos pré-prontos.
- Testes de resistência à vibração e temperatura.
- Firmware quase final:
  1. Últimas correções e ajustes de funcionalidades.
  2. Sincronização confiável com a interface web.
  3. Interface web refinada: Melhorias visuais e de usabilidade.
  4. Gráficos de histórico.
  5. Indicadores de status do dispositivo (ex.: conectado/desconectado).

#### 5º Mês - Versão Final e Entrega
**Objetivo**: Finalizar o dispositivo e preparar para implantação.

**Entregáveis**:
- Protótipo finalizado:
  1. Placa de circuito impressa final (projeto industrial).
  2. Case resistente a água, poeira e vibração.
  3. Firmware completamente funcional e atualizado.
  4. Interface web completa:
     1. Visualização em tempo real e histórico de dados.
     2. Funcionalidade para atualização remota do firmware.
  5. Documentação técnica completa:
     1. Esquemas do hardware.
     2. Código-fonte comentado.
     3. Guia de uso e manutenção.
     4. Testes finais de validação do produto.
  6. Apresentação do protótipo final ao cliente.

## 3. Persona 

&emsp;Personas são descrições fictícias, porém precisas, de possíveis usuários da solução a ser desenvolvida. A análise e criação de personas é um passo fundamental no desenvolvimento de um projeto, independente de seu escopo. A mesma tem a função de guiar o processo de criação, tendo sempre um foco primordial na pessoa que utilizará e manipulará sua solução (Marúas, 1997). Se bem feita, torna o nível de acurácia e satisfação do produto final maior, mais abrangente e satisfatório.

<div align="center">

<sub>Figura 1 - Persona João Silva parte 1 </sub>

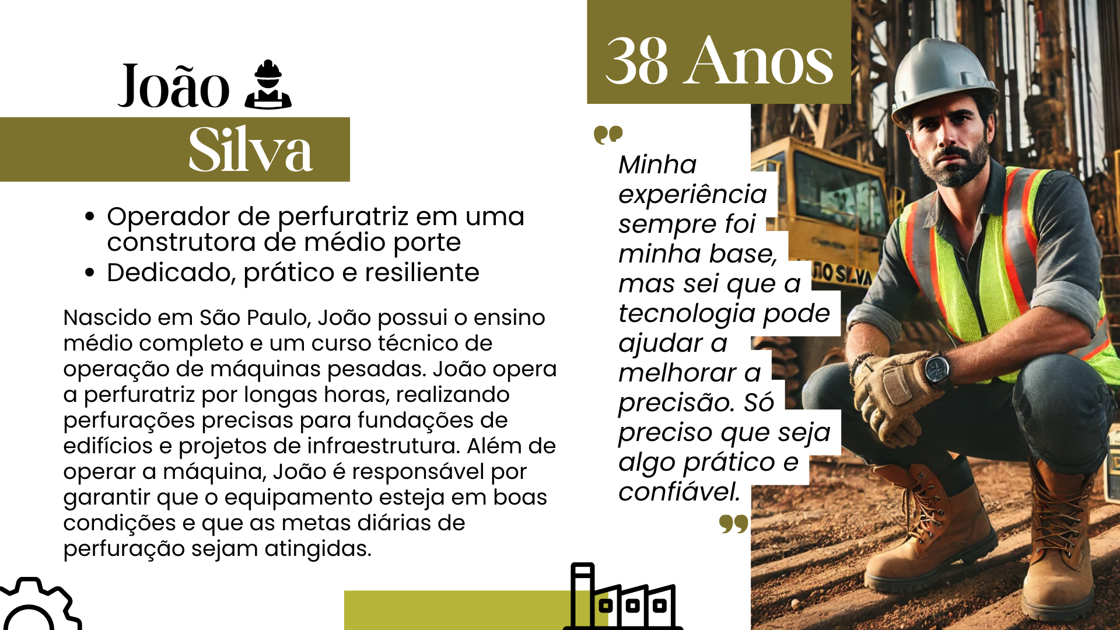
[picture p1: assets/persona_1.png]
   

<sup>Fonte: Material produzido pelos autores (2025)</sup>

</div>

&emsp;João Silva é a principal persona deste projeto. Ele representa justamente o principal usuário do dispositivo: o operador de máquinas pesadas como a perfuratriz. João é um operador natual de São Paulo, com um ensino técnico em operação de maquinário pesado. No seu dia-a-dia, ele opera a perfuratriz por longas horas, realizando perfurações precisas para fundações de edifícios e projetos de infraestrutura. Além de operar a máquina, João é responsável por garantir que o equipamento esteja em boas condições e que as metas diárias de perfuração sejam atingidas.

<div align="center">

<sub>Figura 2 - Persona João Silva parte 2 </sub>

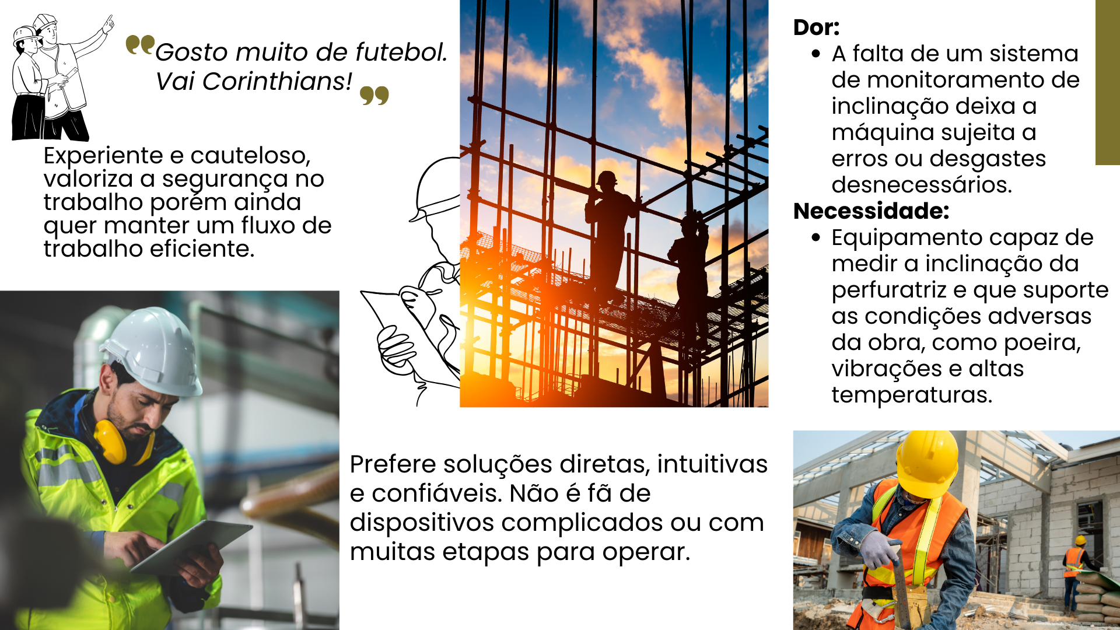
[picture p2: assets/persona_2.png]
   

<sup>Fonte: Material produzido pelos autores (2025)</sup>

</div>

&emsp;João, infelizmente, é Corinthiano... Entretanto, isso não o impede de valorizar extremamente a segurança em seu trabalho. Entretanto, ele sempre gosta de deixar clara a sua intenção de manter a eficiência mesmo com constantes verificações de segurança. Em relação ao uso de tecnologias para facilitar a sua vida, João prefere soluções diretas, que não precisem de muitas etapas para serem utilizadas. Em seu trabalho, a sua maior dor é a falta de um sistema de monitoramento de inclinação deixa a máquina sujeita a erros ou desgastes desnecessários. Sua maior necessidade envolve, dessa forma, um equipamento capaz de medir a inclinação da perfuratriz e que suporte as condições adversas da obra, como poeira, vibrações e altas temperaturas.

&emsp;A criação de João como persona para o projeto é essencial para que seja possível entender as necessidades, desafios e motivações de um público específico que o projeto pretende atingir. Ele possui as características de um trabalhador que é acostumado a operar máquinas pesadas e permite que a solução seja desenvolvida de maneira estratégica para sanar as suas dores. Assim, não é exagero algum dizer que João molda completamente o projeto, definindo muito de como o trabalho será feito.  

## 3.1. Storyboard da persona 
&emsp;De acordo com Gorny (2021), o storyboard é uma ferramenta essencial para antecipar e estruturar narrativas visuais, permitindo que designers identifiquem problemas de usabilidade e fluxo por meio de uma sequência de imagens que representam a interação do usuário. Dessa maneira, no contexto do nosso projeto, o storyboard é utilizado para ilustrar como o produto será utilizado no cotidiano dos usuários, servindo como um guia visual prático. A vantagem de usar imagens é que elas tornam a história fácil de entender à primeira vista e facilitam a memorização.

Em geral, a criação de um storyboard inclui três elementos principais: o cenário, o visual e a legenda.

* Cenário: Os storyboards são baseados em um cenário ou em uma história de usuário, e esse cenário é claramente especificado no topo do storyboard.
* Visual: São as representações gráficas ou ilustrações da interação de cada etapa do cenário.
* Legenda: Cada visual tem uma legenda correspondente. A legenda descreve brevemente as ações do usuário, ambiente, estado emocional, dispositivo e assim por diante.

&emsp;Dessa forma, para o projeto do Inclinômetro Bristol, o storyboard representa uma ótima ferramenta para que se possa entender e ter uma ideia ilustrada de como a pesona utilizaria o dispositivo no dia-a-dia. No caso da persona João Silva, o storyboard é pensando justamente no seu dia de trabalho e consiste em 6 fases principais, sendo elas:

* João chega ao ambiente de trabalho e confere o maquinário
* João acopla o dispositivo na máquina
* João conecta o seu celular ao dispositivo via bluetooth
* As informações de ângulo são visíveis no celular de João
* João entra na cabine de operação da máquina
* Ao mover a máquina, João vê o ângulo se alterando na tela do celular

&emsp;Essas fases representam de maneira genuína e simplificada o fluxo de trabalho de João em uma obra de construção civil que utiliza o Inclinômetro Bristol para medir a inclinação de uma perfuratriz. Tais fases também podem ser vistas de maneira visual abaixo (note que as imagens foram geradas por inteligência artificial, o que pode acarretar em erros e inconsistências):

<div align="center">

<sub>Figura 3 - Storyboard João Silva </sub>

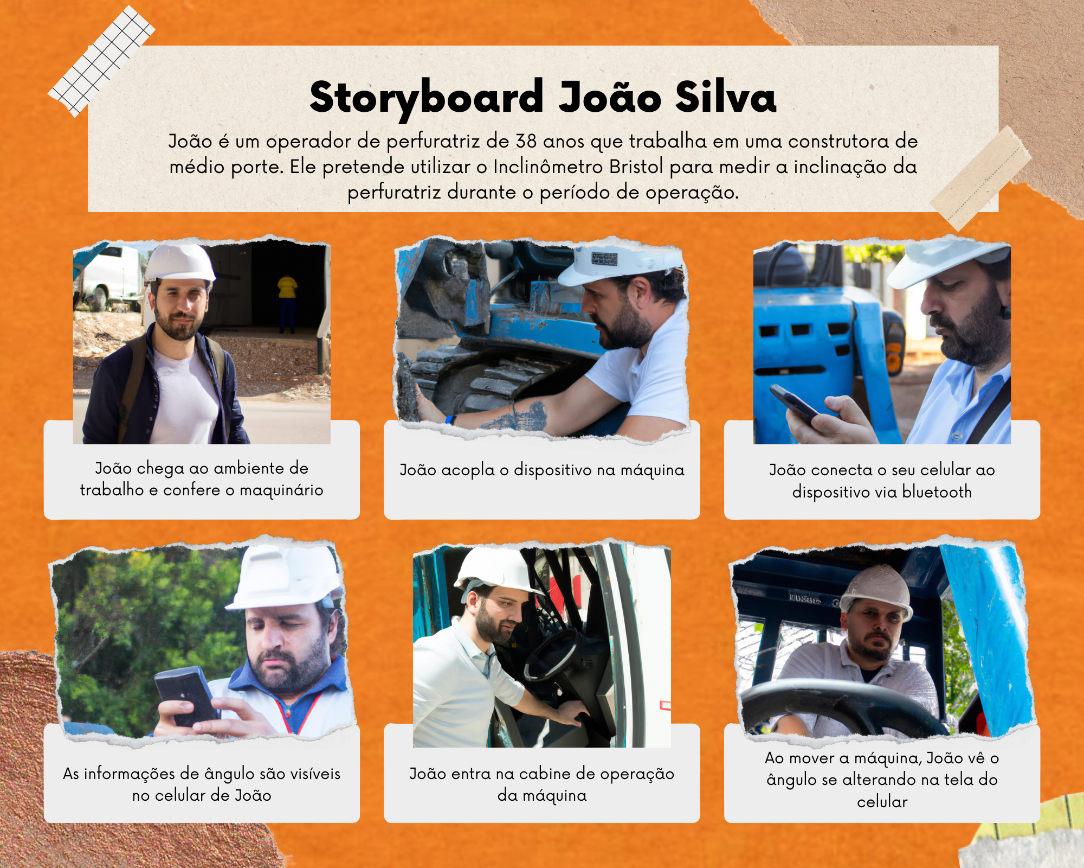
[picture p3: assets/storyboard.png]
   

<sup>Fonte: Material produzido pelos autores (2025)</sup>

</div>

&emsp;A análise do storyboard de João revela insights essenciais sobre as necessidades específicas de sua persona na interação com o dispositivo, destacando a necessidade por melhorar as qualidade de segurança de trabalho enquanto ainda oferece uma solução simples e eficiente. Ao final do desenvolvimento do storyboard, fica claro como cada etapa de interação foi projetada para responder às necessidades e expectativas da persona desse projeto. Ao entender e antecipar as motivações dos usuários, o projeto proporciona uma melhor experiência, que fortalece o engajamento e a confiança no dispositivo e os dados coletados.

## 3.2. User Stories
&emsp;User Stories configuram uma maneira de identificar as funcionalidades que uma persona valoriza em uma solução. Elas possuem o formato "Eu, como {ocupação da persona}, gostaria de {ação}, a fim de que {ganho}.

&emsp;Para a persona João Silva, foram desenvolvidas as seguintes histórias do usuário:

<div align="center">

| User Story (ID) | Descrição (Formato Clássico) | Justificativa | Requisito que Atende (RF/RNF) |
|---|---|---|---|
| US01 | **Como** operador de perfuratriz, **quero** visualizar o ângulo de inclinação em tempo real no celular **para que** eu possa ajustar a posição com segurança e eficiência. | Garante precisão na operação, evitando erros de perfuração e danos à máquina. | RF01, RNF03, RNF04 |
| US02 | **Como** operador em campo, **quero** conectar o dispositivo ao celular via Bluetooth em poucos passos **para que** eu não precise interromper a operação para configurações. | Simplifica o fluxo de trabalho, evitando perda de tempo com configurações complexas. | RF02, RNF07, RNF10 |
| US03 | **Como** operador que lida com vibrações intensas, **quero** que o dispositivo funcione sem falhas sob vibração **para que** as medições não sejam comprometidas. | Assegura confiabilidade em ambientes críticos, onde vibrações são frequentes. | RNF05 |
| US04 | **Como** operador em turnos longos, **quero** monitorar o nível da bateria do dispositivo **para que** ele não desligue durante o uso. | Permite planejamento de recargas, evitando interrupções inesperadas na operação. | RF03, RNF02 |
| US05 | **Como** operador com pouca familiaridade com tecnologia, **quero** uma interface simples no celular com dados essenciais **para que** eu não me distraia com informações irrelevantes. | Reduz a curva de aprendizado e aumenta a eficiência operacional. | RF08, RNF10 |
| US06 | **Como** operador em ambientes com poeira e umidade, **quero** que o dispositivo seja resistente a água e sujeira **para que** ele não quebre devido a fatores externos. | Prolonga a vida útil do equipamento e mantém a precisão em condições adversas. | RNF06 |
| US07 | **Como** operador preocupado com segurança, **quero** receber alertas sonoros e visuais se a inclinação ultrapassar limites **para que** eu possa interromper a operação imediatamente. | Previne acidentes e danos à máquina causados por inclinações perigosas. | RF08, RNF10 |
| US08 | **Como** operador que movimenta a perfuratriz com frequência, **quero** que o dispositivo seja fixado de forma robusta **para que** ele não se solte acidentalmente. | Evita perda ou danos ao dispositivo durante transporte ou operação. | RNF05, RNF06 |
| US09 | **Como** operador que movimenta a perfuratriz em ambiente de construção civil, **quero** que saber o ângulo de inclinação da máquina **para que** eu possa ajustá-la corretamente. | Principal funcionalidade da aplicação. | Todos |

</div>

<p align="center">
<sub>Quadro 1: Requisitos Funcionais -  Material criado e desenvolvido pelo desenvolvedor.</sub><br>
</p>

&emsp;No projeto, cada uma dessas histórias do usuário tem como finalidade auxiliar a entender melhor o que a persona quer e precisa e direcionar o desenvolvimento para acatar tais necessidades. Dessa forma, estas histórias do usuário serão fundamentais para o andamento do projeto, uma vez que cada task/funcionalidade deve ser pensada a fim de cumprir essas histórias.

## 4. Requisitos funcionais e não-funcionais
&emsp;Requisitos funcionais e não funcionais são componentes essenciais no desenvolvimento de sistemas, pois definem tanto as funcionalidades esperadas quanto os padrões de desempenho, segurança e usabilidade necessários para que o sistema atenda plenamente às expectativas dos usuários e às demandas estratégicas do negócio. Estes requisitos formam a base para a arquitetura, direcionam as implementações técnicas e garantem a eficácia do sistema ao longo de seu ciclo de vida.

### 4.1. Requisitos Funcionais
&emsp;Em um projeto de tecnologia, os requisitos funcionais descrevem todas as funcionalidades e serviços que uma solução deve possuir a fim de atender as necessidades do usuário. Dessa forma, os requisitos funcionais devem deixar explícitos o que o produto/sistema deve fazer de maneira que esteja alinhado às regras de negócio.

<div align="center">

| RF#  | Descrição |
|---|---|
| RF01 | O dispositivo deve ser capaz de medir o seu ângulo de inclinação em pelo menos dois eixos (X, Y) |
| RF02 | O dispositivo deve enviar os dados de inclinação via Bluetooth |
| RF03 | O dispositivo deve ser alimentado por bateria recarregável em automóveis |
| RF04 | O dispositivo deve armazenar os dados de medição localmente em um cartão SD |
| RF05 | O dispositivo deve possuir botões para ligar e desligar |
| RF06 | O dispositivo deve possuir leds para indicar atividade e conexão Bluetooth |
| RF07 | O dispositivo deve permitir atualizações de software de maneira remota |
| RF08 | A interface gráfica deve mostrar informações de ângulo e bateria do dispositivo |

</div>

<p align="center">
<sub>Quadro 2: Requisitos Funcionais -  Material criado e desenvolvido pelo desenvolvedor.</sub><br>
</p>

### 4.2. Requisitos não-funcionais
&emsp;Os requisitos não funcionais dizem respeito à qualidade e ao desempenho do sistema. Esses requisitos abordam atributos como usabilidade, segurança, confiabilidade, escalabilidade e eficiência. Por exemplo, um requisito não funcional pode especificar que o cadastro em um sistema deve ser rápido, em um tempo estimado de menos de cinco segundos, e que os dados pessoais dos usuários devem ser criptografados para garantir segurança. Da mesma forma, requisitos como alta disponibilidade, como se, o sistema deve estar disponível 100% (cem por cento) do tempo e escalabilidade para suportar até mil acessos simultâneos são exemplos destas características não funcionais. <br>
&emsp;Neste contexto supramencionado, a principal diferença entre requisitos funcionais e não funcionais é que os requisitos funcionais focam nas tarefas e operações que o sistema deve realizar, enquanto os requisitos não funcionais lidam com a qualidade e as restrições sob as quais essas operações devem ocorrer.

**Utilização de normas ISO:**

&emsp;A sigla ISO significa International Organization for Standardization. Tal organização é responsável por padronizar produtos e serviços ao redor do mundo. As normas definidas por essa organização se mostram de extrema importância uma vez que, num mundo cada vez mais globalizado e com cada país seguindo seus próprios critérios, uma padronização desses critérios auxilia o comércio internacional, promove a concorrência justa e melhora a eficiência a nível global.<br>
&emsp;A ISO25010 é uma norma internacional que define critérios de qualidade para o desenvolvimento de software (Ariele, 2015). Dessa forma, é comum que organizações utilizem tal norma para avaliar a qualidade de seus produtos e verificar quais pontos podem ou devem ser melhorados.<br>
&emsp;Um dos pontos que é abordado na ISO25010 é o Modelo de Qualidade de Produto, que define os critérios para avaliar, especificamente, código e demais recursos presentes no software (Britton, 2021). Alguns dos aspectos de qualidade avaliados neste modelo incluem a confiabilidade do produto, seus requisitos de segurança e a eficiência de uso de recursos (como memória e processamento).

<div align="center">

| **RNF#** | **Descrição** | **Aspecto de Qualidade** |
|---|---|---|
| RNF01 | O dispositivo deve utilizar os três sensores (Acelerômetro, Giroscópio e Magnetômetro) para minimizar erros de medição.  | Precisão |
| RNF02 | A autonomia da bateria deve ser de pelo menos 1 dia em operação contínua. | Eficiência Energética |
| RNF03 | A precisão mínima das medições de ângulo deve ser de 1°. | Precisão |
| RNF04 | Deve ser implementado um filtro de Kalman para melhorar a fusão de dados e reduzir ruídos nas medições. | Funcionalidade e Precisão |
| RNF05 | O sistema deve ser resistente a vibrações intensas e a temperaturas de até 50 °C. | Confiabilidade |
| RNF06 | O dispositivo deve ter proteção contra água e poeira (equivalente a uma classificação IP65 ou superior). | Manutenibilidade |
| RNF07 | O dispositivo deve ser capaz de transmitir dados via Bluetooth em tempo real com um alcance mínimo de 10 metros. | Desempenho |
| RNF08 | O design do hardware deve garantir segurança elétrica e conformidade com normas de certificação, como a CE. | Segurança e Conformidade |
| RNF09 | O dispositivo deve ter um tempo de resposta máximo de 200 ms para a transmissão de dados. | Desempenho |
| RNF10 | O aplicativo deve ser intuitivo e de fácil uso, permitindo conexão rápida ao dispositivo. | Usabilidade |

</div>

<p align="center">
<sub>Quadro 3: Requisitos Não-Funcionais -  Material criado e desenvolvido pelo desenvolvedor.</sub><br>
</p>

<div align="center">

&emsp;Cada um desses requisitos não funcionais pode ser testado individualmente, a fim de garantir a funcionalidade correta do dispositivo.

| **RNF** | **Método de Teste** |
|---|---|
| **RNF01** | Realizar testes comparativos entre leituras individuais do acelerômetro, giroscópio e magnetômetro e a fusão dos três sensores. Validar a redução de erros na medição combinada. |
| **RNF02** | Colocar o dispositivo em operação contínua em condições típicas de uso (sensores ativos, transmissão Bluetooth) e medir o tempo de autonomia da bateria até o esgotamento. |
| **RNF03** | Calibrar o sistema com um dispositivo de referência (como um inclinômetro industrial, ou, em casos mais simples, até mesmo um transferidor) e validar se os valores medidos têm uma variação máxima de ±1°. |
| **RNF04** | Implementar o filtro de Kalman e comparar as leituras do sistema com e sem o filtro em ambientes com ruído (como vibrações). Verificar a estabilidade e precisão dos valores. |
| **RNF05** | Submeter o dispositivo a condições de vibração (com uma máquina de vibração ou superfície de teste) e temperaturas de até 50 °C, monitorando a consistência das medições. |
| **RNF06** | Realizar testes de imersão leve e exposição a poeira, simulando condições equivalentes a IP65. Verificar o funcionamento normal do dispositivo após os testes. |
| **RNF07** | Testar a transmissão de dados via Bluetooth em diferentes distâncias (até 10 metros) e ambientes variados (com obstáculos e interferências). Validar a recepção estável dos dados. |
| **RNF08** | Verificar se os circuitos eletrônicos atendem a padrões de certificação CE, como isolamento, proteção contra curto-circuito e testes de segurança elétrica. |
| **RNF09** | Monitorar o tempo de transmissão dos dados (desde a captura pelo sensor até a exibição no aplicativo) usando ferramentas de medição de latência. Confirmar que não excede 200 ms. |
| **RNF10** | Realizar testes de usabilidade com operadores reais, verificando o tempo necessário para conectar o dispositivo e começar a receber dados. Observar possíveis dificuldades na interface. |

</div>

<p align="center">
<sub>Quadro 4: Testes dos Requisitos Não-Funcionais -  Material criado e desenvolvido pelo desenvolvedor.</sub><br>
</p>

## 5. Arquitetura simplificada da solução
&emsp;Em projetos de tecnologia, o processo de definir uma arquitetura é de suma importância, uma vez que esta arquitetura dita como os processos de desenvolvimento seguirão, definindo tecnologias, métodos, paradigmas de desenvolvimento, etc. Dessa forma, essa seção tem como objetivo detalhar brevemente todos os componentes que estão listados para serem utilizados na solução, como que cada um desses componentes ajuda a satisfazer os requisitos funcionais e não-funcionais e também documentar as tecnologias que serão utilizadas, envolvendo linguagens de programação, tecnologias de transmissão sem fio, algoritmos, etc. 

### 5.1. Lista de componentes (Bill of Materials)
&emsp;A lista de materiais, ou BOM (do inglês *Bill of Materials*) consiste em uma tabela de todos os componentes que pretende-se utilizar no dipositivo. Uma versão em planilha pode ser encontrada no link: https://docs.google.com/spreadsheets/d/1ozrlB3lih4T1Wbghi2Zi2bKn9VV_Soy1v98KHoGc6X8/edit?gid=0#gid=0

<div align="center">

| Nome | Preço | Quantidade | Link de Compra |
|---|---|---|---|
| ESP32-WROOM | R$ 41,90 | 2 | [Link](https://www.robocore.net/wifi/esp32-wifi-bluetooth) |
| Acelerômetro, Giroscópio e Magnetômetro MPU-9250 | R$ 79,90 | 2 | [Link](https://www.robocore.net/sensor-robo/acelerometro-giroscopio-magnetometro-mpu9250) |
| Lithium Battery Detection Module, LiPo Fuel Gauge, A, D Conversão, IIC, MAX17043 | R$ 17,82 | 2 | [Link](https://pt.aliexpress.com/item/1005006386540902.html) |
| Mini Módulo Cartão Micro SD | R$ 4,90  | 2 | [Link](https://www.eletrogate.com/mini-modulo-cartao-micro-sd) |
| Módulo Carregador de Baterias de Lítio TP4056 com Proteção - USB-C | R$ 6,90  | 2 | [Link](https://www.eletrogate.com/modulo-carregador-de-baterias-de-litio-tp4056-com-protecao-usb-c) |
| Módulo Regulador de Tensão Ajustável LM2596 3A | R$ 7,50  | 2 | [Link](https://www.robocore.net/regulador-de-tensao/modulo-regulador-de-tensao-ajustavel-lm2596-3a) |
| Regulador de Tensão 7805 5V | R$ 2,90  | 3 | [Link](https://www.makerhero.com/produto/regulador-de-tensao-7805-5v/) |
| Bateria Li-Ion 18650 3,7V 2500mAh 2C | R$ 39,90 | 2 | [Link](https://www.robocore.net/bateria/bateria-li-ion-18650-37v-2500mah) |
| Valor total | R$ 406,34 |

</div>

<p align="center">
<sub>Quadro 5: Bill of Materials -  Material criado e desenvolvido pelo desenvolvedor.</sub><br>
</p>

### 5.2. Utilização de cada componente
&emsp;Cada componente em um projeto de tecnologia não é escolhi arbitrariamente, mas sim com o propósito de satisfazer cada um dos requisitos estabelecidos. Dessa forma, a tabela abeixo demonstra como cada um dos componentes da lista de materiais ajuda o dispositivo a se aproximar do seu objetivo final.

<div align="center">

| Nome | Requisito que atende | Como atende |  
|---|---|---|
| ESP32-WROOM | **RNF07**, **RNF09** | Garante transmissão Bluetooth em tempo real (10m) e processamento rápido para tempo de resposta ≤200 ms |  
| Acelerômetro, Giroscópio e Magnetômetro MPU-9250 | **RNF01**, **RNF03**, **RNF04** | Fornece dados triaxiais para fusão sensorial (minimiza erros), permite precisão de 1° e integra-se ao filtro de Kalman |  
| Lithium Battery Detection Module, LiPo Fuel Gauge, A, D Conversão, IIC, MAX17043 | **RNF02** | Monitora carga da bateria em tempo real para otimizar consumo e garantir autonomia de 24h |  
| Mini Módulo Cartão Micro SD | **RNF05** | Armazena dados localmente durante falhas de transmissão, mantendo operação sob vibrações |  
| Módulo Carregador de Baterias de Lítio TP4056 com Proteção - USB-C | **RNF08** | Protege contra curto-circuitos e sobrecargas, garantindo conformidade com padrões de segurança |  
| Módulo Regulador de Tensão Ajustável LM2596 3A | **RNF02**, **RNF05** | Estabiliza alimentação (5V) para eficiência energética e resistência a variações térmicas |  
| Regulador de Tensão 7805 5V | **RNF08** | Adapta tensão de entrada (até 20V) para 5V fixos, seguindo normas de segurança elétrica |  
| Bateria Li-Ion 18650 3,7V 2500mAh 2C | **RNF02** | Fornece 5000mAh total (2x2500mAh) para suportar 24h de operação contínua |  

</div>

<p align="center">
<sub>Quadro 6: Como cada componente satisfaz os requisitos -  Material criado e desenvolvido pelo desenvolvedor.</sub><br>
</p>

* Nota: RNF06 e RNF10 precisam de ações complementares (design físico ou desenvolvimento de software).

### 5.3. Tecnologias utilizadas
&emsp;As tecnologias utilizadas em um projeto como este desempenham um papel fundamental no sucesso do projeto. A utilização de uma linguagem ou framework não eficiente pode custar tempo e dinheiro. Dessa forma, é vantajoso estudar, escolher e listar quais as melhores tecnologias para resolver o problema de acordo com seus requisitos. A tabela abaixo demonstra as tecnologias utilizadas no projeto.

<div align="center">

| Tecnologia | Descrição | Requisitos Atendidos (RNF)  |
|---|---|---|
| **Linguagem** | **C++ (Arduino Framework)**: Ideal para programação de microcontroladores e integração com sensores. | RNF04, RNF07, RNF09 |
| **Bibliotecas** | - **MPU9250_light**: Leitura de dados do acelerômetro/giroscópio/magnetômetro.<br>- **Kalman Filter Library**: Implementação do filtro de Kalman.<br>- **ArduinoBLE**: Transmissão Bluetooth BLE.<br>- **ArduinoOTA**: Atualizações de firmware via Wi-Fi/Bluetooth.<br>- **SD**: Armazenamento de dados no cartão Micro SD. | RNF01, RNF04, RNF07, RNF09  |
| **Paradigmas** | - **Programação Orientada a Objetos (POO)**: Para modularizar código (ex: classes para sensores, comunicação).<br>- **Multitarefa Assíncrona**: Usando `FreeRTOS` para gerência de threads (leitura de sensores, Bluetooth, OTA). | RNF09, RNF05 |
| **Framework** | **Flutter (Dart)**: Para desenvolvimento multiplataforma (Android/iOS) com suporte a BLE.<br>| RNF10 |
| **Bibliotecas** | - **flutter_blue**: Comunicação Bluetooth BLE.<br>- **Charts**: Exibição gráfica da inclinação em tempo real. | RNF07, RNF10 |
| **Filtro de Kalman** | - Implementação customizada para fusão de dados do MPU9250 (acelerômetro + giroscópio + magnetômetro).<br>- **Biblioteca Eigen**: Para operações matriciais (opcional, se usar C++ puro). | RNF01, RNF03, RNF04 |
| **Cálculo de Ângulo**| - Uso de **quaternions** para representação 3D da orientação, evitando *gimbal lock*. | RNF03, RNF05 |
| **MAX17043 Library** | - Monitoramento preciso da bateria (carga, tensão).<br> | RNF02, RNF05 |
| **Estratégias** | - Desligamento de periféricos não críticos (ex: SD card) quando a bateria está baixa. | RNF02 |
| **ArduinoOTA** | - Atualizações via Wi-Fi ou Bluetooth (dependendo da disponibilidade da rede no local).<br>- **Servidor HTTP**: Hospedagem do firmware (ex: usando ESP32 como servidor web). | RNF07, RNF09 |
| **Plataformas** | - **Wokwi**: Simulação inicial do circuito e lógica.<br>- **PlatformIO**: Ambiente de desenvolvimento com testes unitários e integração contínua. | RNF04, RNF05 |
| **Prototipagem** | - **KiCad**: Para esquematizar e desenhar a placa de circuito do dispositivo.<br> | Todos |

</div>

<p align="center">
<sub>Quadro 7: Tecnologias e métodos utilizados no desenvolvimento da solução -  Material criado e desenvolvido pelo desenvolvedor.</sub><br>
</p>

## 6. Desenvolvimento contínuo do projeto
&emsp;Esta seção tem como objetivo falar sobre o desenvolvimento contínuo do projeto e da solução. Dessa forma, este é um espaço utilizado para discutir os avanços feitos a cada semana/mês, entregas que foram feitas com sucesso, impedimentos, problemas encontrados, etc. 

### 6.1. Primeira semana de projeto
&emsp;O começo do projeto foi marcado por todo o processo de estruturação. Este documento foi criado e preenchido até a seção 5.3. Além disso, foi realizada a compra de todos os componentes que serão necessários para a primeira fase do projeto. <br>
&emsp;A principio, está sendo realizado um estudo mais aprodundado de como utilizar o sensor MPU9250 para realizar a leitura do ângulo de inclinação do dispositivo. Algumas fontes incluem vídeos de uma playlist onde um drone é construído. Este drone utiliza sensores MPU6050 (Acelerômetro e Giroscópio) para medir o ângulo do drone e estabilizá-lo. Além disso, é daí que surgiu a ideia de utilizar um filtro Kalman para estabilizar as medições do sensor. Vale a pena assistir:
- [5 -  How to calibrate the MPU6050 with Arduino and Teensy](https://www.youtube.com/watch?v=Yh6mYF3VdFQ&list=PLeuMA6tJBPKsAfRfFuGrEljpBow5hPVD4&index=7)
- [14 -  Measure angles with the MPU6050 accelerometer](https://www.youtube.com/watch?v=7VW_XVbtu9k&list=PLeuMA6tJBPKsAfRfFuGrEljpBow5hPVD4&index=17)
- [15 -  Combine a gyroscope and accelerometer to measure angles - precisely](https://www.youtube.com/watch?v=5HuN9iL-zxU&list=PLeuMA6tJBPKsAfRfFuGrEljpBow5hPVD4&index=18)

&emsp;Por enquanto, apenas uma coisa pode ser feita até que os componentes eletrônicos comprados cheguem: simulações de software. Para isso, está sendo utilizado o software Wokwi, um poderoso simulador de projetos IOT com ESP32. Assim, este é o próximo passo de desenvolvimento. 

### 6.2. Primeiro mês de execução do projeto

&emsp;Após a primeira semana de projeto, os componentes de hardware comprados foram finalmente entregues e foi possível, então, começar a trabalhar em um protótipo físico já em uma mini-protoboard. O trabalho na protoboard envolveu fazer as ligações físicas do microcontrolador ESP32, o IMU MPU9250, a placa de carregamento TP4056 e a bateria do dispositivo, uma célula de lítio 18650 3.6V 2500mAh. As ligações na protoboard seguiram um esquemático semelhante ao do esquemático presente na simulação (Seção 7), com a adição do circuito de carregamento e bateria. Dessa forma, o circuito montado na protoboard pode ser visto no vídeo disponível no <a href="https://drive.google.com/file/d/1-cZsZ9_ApUcqNGR_vv2ISyXd2w9-_lHn/view?usp=sharing">link</a>.

&emsp;É importante dizer que esta primeira versão funcionava bem apenas quando conectada via USB ao computador, ou seja, não funcionava apenas com a bateria. Isso acontecia por conta de um booster de má qualidade que estava sendo usado para aumentar a tensão da bateria para alimenta o ESP32. O booster é um dispositivo eletrônico que consegue receber um nível de tensão e enviar um nível mais alto. Como a tensão da bateria varia entre 4.2 e 3.6 volts e o microcontrolador precisava de 5 volts, a ideia era usar o booster para aumentar a tensão da bateria para este valor. Entretanto, o booster introduziu um ruído significativo no circuito do microcontroaldor, o que fez com a sua interface I2C (responsável pela conexão do sensor IMU MPU9250) não funcionasse. Assim, a solução foi remover o booster e alimentar o ESP32 diretamente com a bateria, algo que pareceu funcionar bem.

&emsp;Além de montar todo o circuito físico, o primeiro mês de desenvolvimento também contou com o desenvolvimento do software que, utilizando o filtro de Kalman, faz a fusão dos dados de acelerômetro e giroscópio nos dá um valor de ângulo consideravelmente estável. Com tal software, foi possível atingir uma precisão de aproximadamente 0.1 grau. O código dessa primeira versão pode ser encontrado na pasta src/Inc-Bristol-Fisico-0001 deste projeto, e está no formato de um projeto do Platform IO (uma extensão para VS Code que é utilizada para desenvolver para microcontroladores). O código está dividido em arquivos source (.cpp) e headers (.h), onde os primeiros contam com a lógica do código e os segundos trazem as definições das funções para que os arquivos sejam importados, trazendo modularidade ao projeto. 

* src/Inc-Bristol-Fisico-0001/include/BluetoothLowEnergy.h: Definições de funções para as funções de bluetooth low energy do microcontrolador.
* src/Inc-Bristol-Fisico-0001/include/Config.h: Definições de configurações gerais do código, como portas, endereços I2C, valores para filtro de Kalman.
* src/Inc-Bristol-Fisico-0001/include/DataProcessor.h: Definições para módulo responsável por realizar os cálculos com dados vindos do sensor.
* src/Inc-Bristol-Fisico-0001/include/KalmanFilter.h: Definições de funções para a classe do filtro de Kalman, que realiza as predições de ângulos (estabiliza a medição do ângulo).
* src/Inc-Bristol-Fisico-0001/include/SensorManager.h: Definições para módulo responsável por interagir com o sensor MPU9250.

* src/Inc-Bristol-Fisico-0001/src/BluetoothLowEnergy.cpp: código fonte para as funções de envio de dados com o bluetooth low energy.
* src/Inc-Bristol-Fisico-0001/src/DataProcessor.cpp: código fonte para o processamento de dados que vêm do sensor MPU9250, realiza cálculos de pitch e roll, por exemplo.
* src/Inc-Bristol-Fisico-0001/src/KalmanFilter.cpp: Todo o código bruto para se implementar o filtro de Kalman, incluindo seus cálculos matriciais. 
* src/Inc-Bristol-Fisico-0001/src/SensorManager.cpp: Código fonte que abstrai a biblioteca do MPU9250 para acessar os dados do sensor MPU9250.
* src/Inc-Bristol-Fisico-0001/src/main.cpp: Este é o arquivo principal, o nosso "entry-point". Aqui, são importados os módulos e o microcontrolador é configurado e todas as funções são chamdas. No loop, os valores de ângulo são filtrados pelo Filtro de Kalman e os valores são enviados via bluetooth. 

&emsp;Além da documentação presente aqui, o código se suficientemente comentado e bem escrito para que se possa entender o seu funcionamento de maneira clara e direta. Como dito anteriormente, essa versão do software se mostrou promissora e retornou valores de ângulos precisos e estáveis. Entretanto, tais medições ainda não foram testadas em máquinas, então é difícil saber se o funcionamento continuará satisfatório em ambientes de alta vibração. Uma primeira demonstração da medição de ângulo com a versão do inclinômetro em proboard pode ser visto no seguinte <a href="https://drive.google.com/file/d/1TFvWR8d0liu2skIPtGLhfb_HX8xHarvI/view?usp=sharing">link</a>.

&emsp;Para além do desenvolvimento da versão inicial em protoboard e do firmaware, uma das metas do primeiro mês de desenvolvimento seria já desenvolver uma versão inicial de uma placa de circuito impresso. Assim, a primeira versão foi prototipada no KiCAD e fabricada em uma prototipadora própria. Os esquemáticos, desenhos e placa finalizada podem ser vistos nas figuras abaixo:

<div align="center">

<sub>Figura X - Esquemático da PCI inicial </sub>

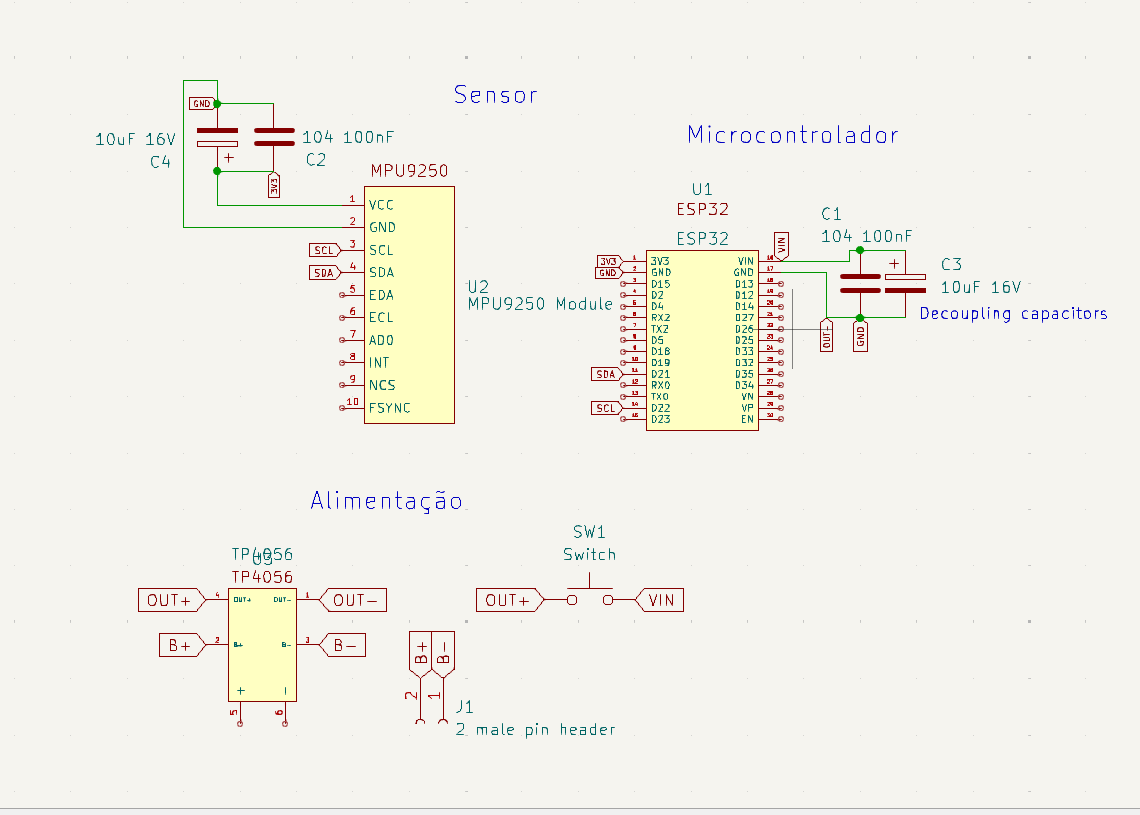
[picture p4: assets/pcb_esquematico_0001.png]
   

<sup>Fonte: Material produzido pelos autores (2025)</sup>

</div>

<div align="center">

<sub>Figura X - Desenho da PCI inicial </sub>

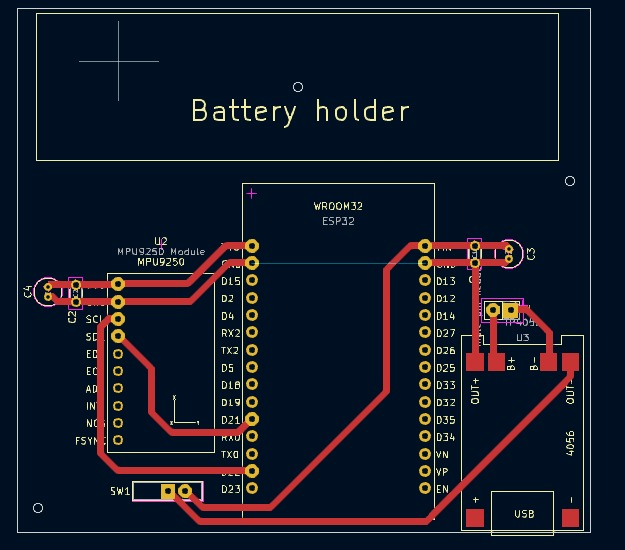
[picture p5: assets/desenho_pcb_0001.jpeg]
   

<sup>Fonte: Material produzido pelos autores (2025)</sup>

</div>

<div align="center">

<sub>Figura X - PCI inicial </sub>

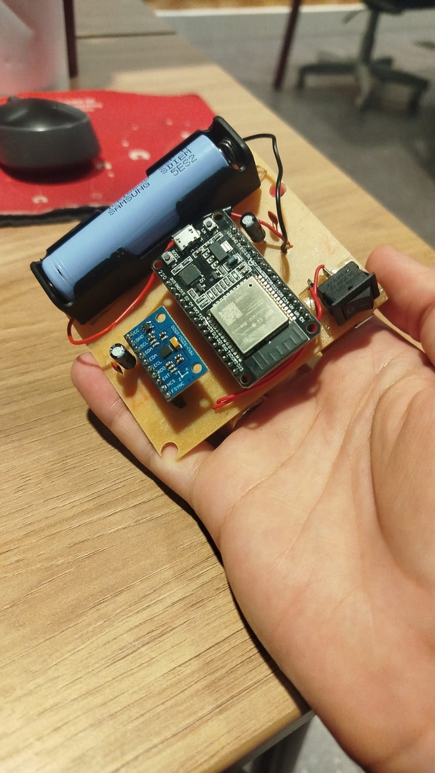
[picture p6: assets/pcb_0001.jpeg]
   

<sup>Fonte: Material produzido pelos autores (2025)</sup>

</div>

&emsp;A placa foi feita, testada e funcionou corretamente. Entretanto, alguns pontos de melhoria foram notados:
* O tamanho dos furos para parafusos ficou muito grande. 
* O posicionamento da bateria não ficou ideal. A proposta é colocar a bateria do outro lado pra deixar USB livre.
* Deixar componentes mais próximos, fazer placa menor (principalmente capacitores).
* Posicionamento do interruptor também não ficou ideal.

&emsp;Dessa forma, foi desenvolvida uma segunda versão da PCI, que conta com os exatos componentes da versão anterior, porém arranjados de maneira diferente. Além disso, foi decidido remover o espaço para bateria da placa, a fim de deixá-la menor (a bateria ainda estará presente no case, mas não em cima da placa).

<div align="center">

<sub>Figura X - Desenho da PCI inicial 2.0 </sub>

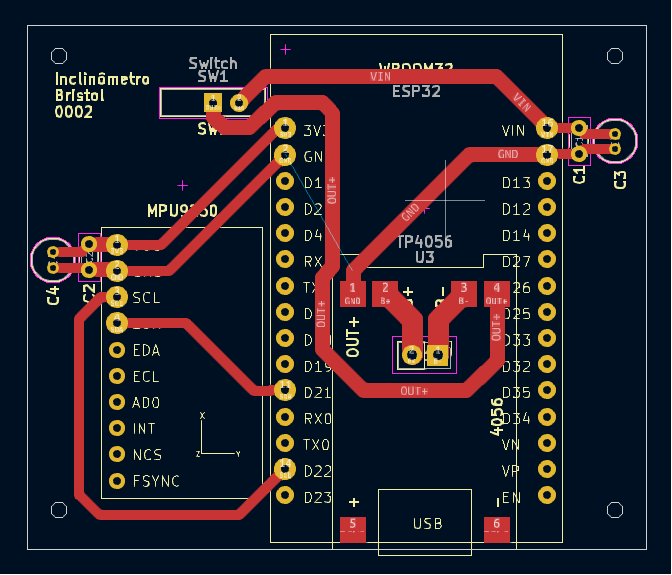
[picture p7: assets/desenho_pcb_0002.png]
   

<sup>Fonte: Material produzido pelos autores (2025)</sup>

</div>

&emsp;Note que, como nessas versões iniciais o footprint (texto em cima da placa) não é impresso, não é um problema que ele esteja sobreposto em alguns pontos. Para a versão final e industrial, é de suma importância que o footprint esteja adequado, uma vez que ele dá várias instruções sobre a montagem da placa e seu funcionamento. Assim, a segunda versão da placa ficou assim:

<div align="center">

<sub>Figura X - PCI inicial 2.0 </sub>

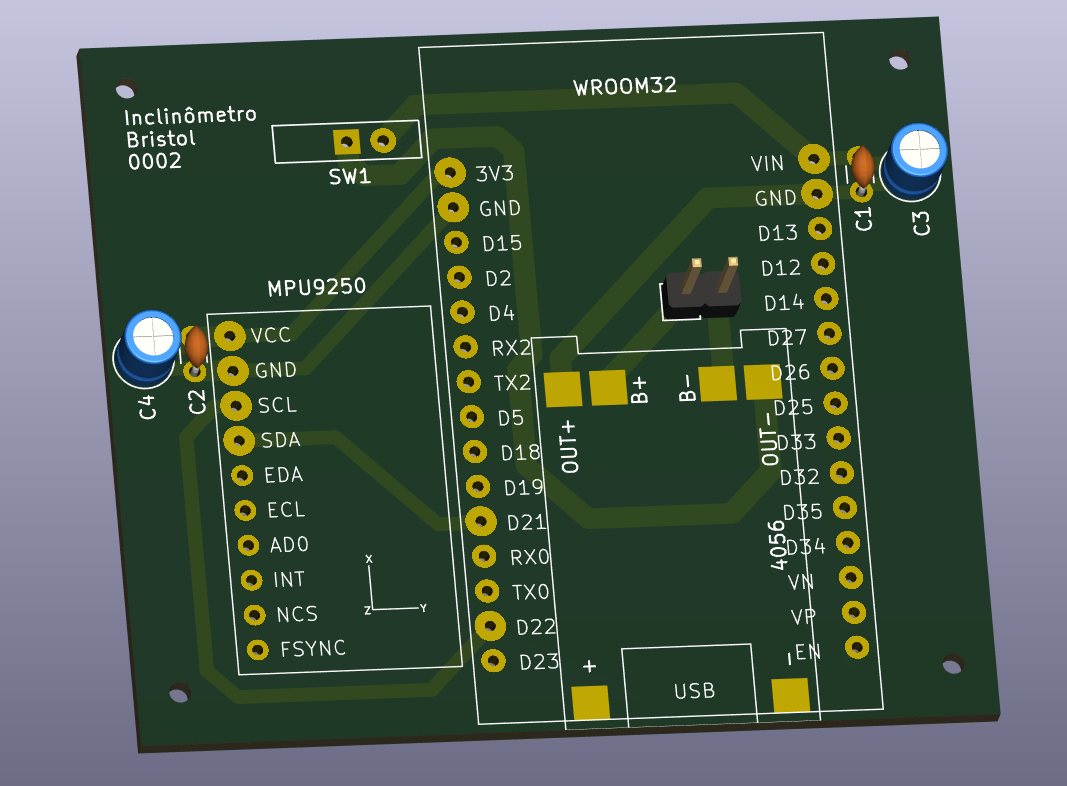
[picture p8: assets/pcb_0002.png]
   

<sup>Fonte: Material produzido pelos autores (2025)</sup>

</div>

&emsp;Para alémm da placa de circuito, que funcionou melhor do que a anterior (apesar de ainda precisar de ajustes), também foi desenvolvido um case provisório, impresso em impressora 3D.

<div align="center">

<sub>Figura X - PCI inicial 2.0 </sub>

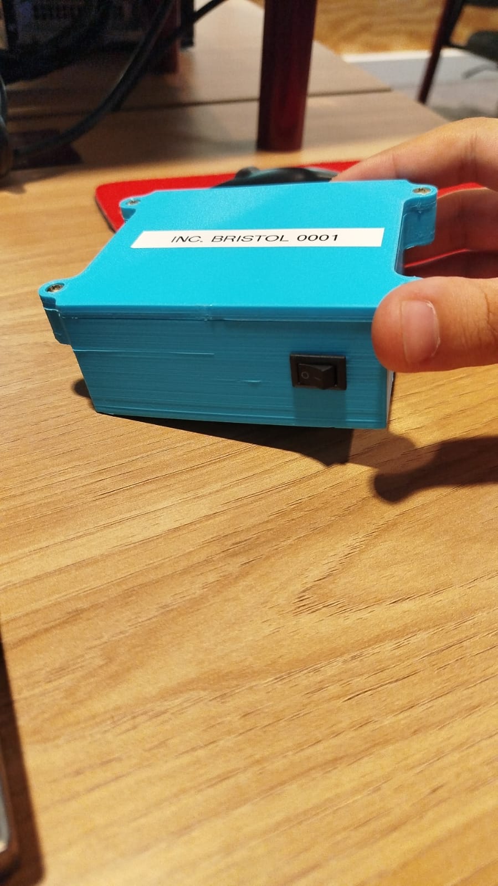
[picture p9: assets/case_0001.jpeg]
   

<sup>Fonte: Material produzido pelos autores (2025)</sup>

</div>

&emsp;Dessa forma, o dispositivo desenvolvido no primeiro mês cumpriu todoso os requisitos que foram definidos como entregáveis de primeiro mês, incluindo:
* Protótipo inicial em protoboard
* Protótipo inicial em PCI simples
* Código inicial que lê os valores de ângulo do MPU9250
* Firmware que calcula o ângulo do dispositivo com Filtro de Kalman e envia dados via bluetooth low energy
* Circuito de carregamento de bateria
* Case inicial, ainda não resistente a poeira e vibrações

&emsp;Por fim, a única coisa ainda não desenvolvida no primeiro mês foram os testes em uma máquina real, algo importante a fim de entender como as vibrações afetam a medição dos ângulos. 

### 6.3. Segundo mês de execução do projeto
&emsp;Para o segundo mês de projeto, como é de se esperar, o foco foi em desenvolver e entregar tudo aqui que foi combinado para o segundo mês na seção 2.1 deste documento. Além disso, o dispositivo desenvolvido no primeiro mês foi enviado para a Bristol a fim de que fossem realizadas testagens com uma perfuratriz de verdade, de modo a entender a precisão de medição do ângulo proveniente do dispositivo.

&emsp;Após lidar com o envio, o próximo passo foi recomeçar a montagem de um novo dispositivo, que dessa vez deveria incluir:
* Leds indicativos;
* Leitor de cartão SD;
* Leitor de carga da bateria

&emsp;Assim, da mesma maneira como foi feito no primeiro mês, primeiro foi desenvolvido o circuito em protoboard, a fim de validar o seu funcionamento. O leitor de cartão SD utiliza a interface SPI do microcontrolador, já o leitor de carga da bateria utiliza o I2C, o mesmo utilizado pelo MPU9250. Dessa forma, as conexões foram feitas e um códio inicial para validar todo o funcionamento foi desenvolvido. Ao final desse processo, foi possível constatar que o circuito proposto funcionava.

&emsp;Tendo o circuito funcionando em protoboard, a próxima etapa foi desenvolver a placa de circuito impressa. O desenvolvimento dessa placa de mostrou especialmente difícil, uma vez que, por conta das limitações das ferramentas de trabalho, só era possível projetar placas de uma cada. Assim, e por conta do aumento da quantidade de componentes e conexões, realizar o roteamente (ligação de trilhas) na placa de circuito levou um tempo considerável, e, mesmo ao final, uma trilha ficou sem rota e teve que ser feita via jumper uma vez que a placa ficou pronta. Esse tipo de problema, no entanto, dificilmente acontecerá nos próximos meses, onde haverá um foco em desenvolver uma placa de maneira industrial, utilizando de *pelo menos* 2 camadas.

<div align="center">

<sub>Figura X - Placa de Circuito Impresso desenvolvida no segundo mês </sub>

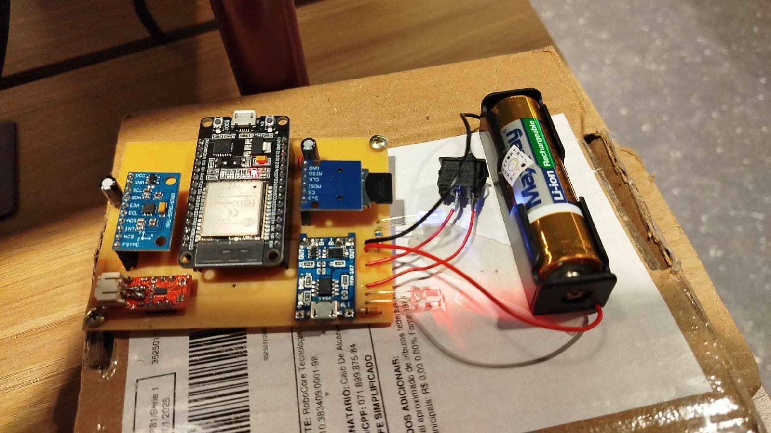
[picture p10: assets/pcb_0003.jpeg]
   

<sup>Fonte: Material produzido pelos autores (2025)</sup>

</div>

&emsp;Com a placa pronta, foi necessário trabalhar no firmware que está presente neste repositório, ou seja, implementar as funcionalidades de leitura de carga de bateria e envio via bluetooth e também o armazenamento dos dados no cartão SD. <br>
&emsp;Para a leitura de carga, simplesmente foi utilizada uma biblioteca própria para o dispositivo, que permite receber o chamado "State of Charge" e a tensão da bateria. Alguns podem se perguntar "Por que usar um sensor específico para a bateria e não apenas medir diretamente a tensão dela com um ESP32 e um divisor de tensão?". Bom, a resposta para essa pergunta jaz no funcionamento das baterias de íons de lítio. Tais baterias operam com uma tensão de varia de cerca de 3.2V (descarregada) a 4.2V (100% carregada). Entretanto, essas baterias não descarregam de maneira linear, o que quer dizer que, por exemplo, 3.7V não necessariamente significam 50% de carga. Por conta disso, utilizamos o CI MAX17043 para realizar a medição do State Of Charge, que utiliza um algorítmo próprio para estimar a carga, em porcentagem, da bateria. <br>
&emsp;Em relação ao leitor de cartão SD, foi necessário incluir a biblioteca da interface SPI e do cartão SD no projeto. Após isso, foi simplesmente necessário verificar a existência dos arquivos e começar a escrever os dados neles após cada leitura. Os arquivos estão em formato CSV (valores separados por vírgula) uma vez que isso facilita a leitura. Um formato assim também facilita, por exemplo, a colocar esses dados em modelos de Machine Learning para realizar análises. É um formato que pode ser aberto como planilha facilmente também. É necessário explicar que a falta de um cartão SD não interrompe a funcionalidade do dispositivo. Caso um cartão SD não seja encontrado, os dados simplesmente não serão armazenados, mas o restante funciona normalmente. <br>
&emsp;Finalizando este trecho, é importante comentar sobre os problemas que foram encontrados. O CI MAX17043, funcionando em conjunto com o MPU9250, apresentou alguns problemas. Até onde foi possível entender, o CI precisa de um intervalo de pelo menos 500ms entre aquisições de dados para poder funcionar corretamente. Além disso, caso o MPU9250 envie dados de maneira constante, sem nenhum atraso, a comunicação com IC falha de modo em que ele lê apenas um valor quando o microcontrolador é ligado e depois não atualiza tal valor nunca mais. Para resolver esse problema, adicionei um intervalo de 1s entre leituras do CI, algo que não deve ser um problema, até porque a carga da bateria não é algo que precisa ser atualizado a cada instante pro usuário. Além disso, foi necessário atualizar um intervalo de 150ms entre cada leitura do MPU9250, o que pareceu afetar as leituras. Será necessário trabalhar para ajustar isso. <br>
&emsp;O último teste feito diretamente no dispositivo foi um teste de carga de bateria. Neste teste, a bateria foi carregada até a sua capacidade máxima (neste caso, o CI estava marcando cerca de 91% de carga). Após isso, o dispositivo foi ligado, com todos os seus periféricos em funcionamento (MPU9250, MPU9250, Cartão SD) e conectado via bluetooth em um celular. O dispositivo ficou, de maneira ininterrupta, por cerca de 6 horas envinando dados de maneira contínua e sem apresentar erros. Ao final deste período, apresentava uma carga de bateria de aproximadamente 30%. Foi interessante ver que o dispositivo não falhou em nenhum momento da exeucução, porém o ideal é que a bateria dure mais. Para isso, foram realizados alguns cálculos considerando o consumo de todos os componentes do circuito. Assim, chegou-se a uma conclusão que uma bateria de 3500mAh, em tese, deve ser capaz de suprir o dispositivo por pelo menos 20h, uma autonomia satisfatória. <br>
&emsp;Um outro tópico importante que foi desenvolvido durante este segundo mês foi um aplicativo mobile, ainda em versão simples, que pode ser utilizado para conectar no dispositivo e visualizar os dados em tempo real na tela do celular de maneira graficamente mais amigável. Tal aplicativo foi feito utilizando a liguagem Dart e o framework Flutter, famoso por permitir desenvolver aplicativos que funcionam tanto para IOS como Android. Detalhes técnicos acerca da implementação do aplicativo não serão discutidos nessa documentação, mas ele conta com a capacidade de:
* Procurar dispositivos Bluetooth próximos, porém só mostra na tela os dispositivos que comecem com o nome "Inclinômetro Bristol";
* Se conectar a um dispositivo do tipo Inclinômetro Bristol;
* Mostrar os dados de inclinação em X e Y provenientes do dispositivo;
* No momento, o aplicativo NÃO mostra dados reais de nível de bateria, mas sim um valor falso fixo em 50%.

&emsp;Abaixo, é possível ver fotos das telas dessa primeira versão do aplicativo. 

<div align="center">

<sub>Figura X - Tela 1 da versão inicial do app do Inclinômetro Bristol </sub>

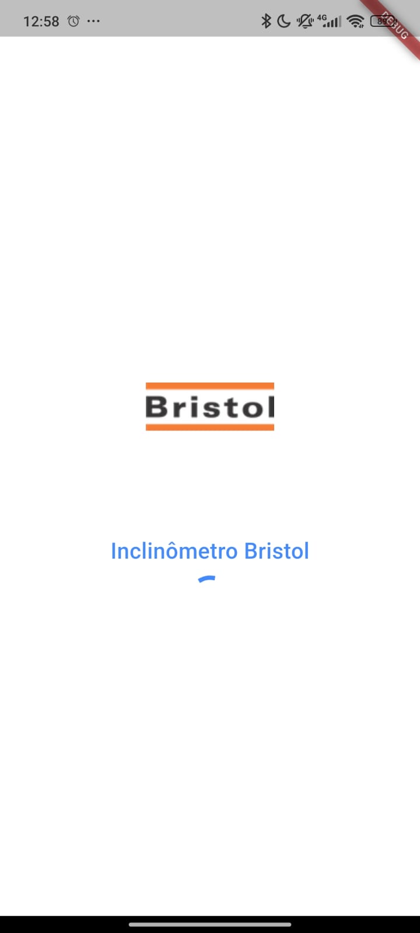
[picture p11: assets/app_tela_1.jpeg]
   

<sup>Fonte: Material produzido pelos autores (2025)</sup>

</div>

<div align="center">

<sub>Figura X - Tela 2 da versão inicial do app do Inclinômetro Bristol </sub>

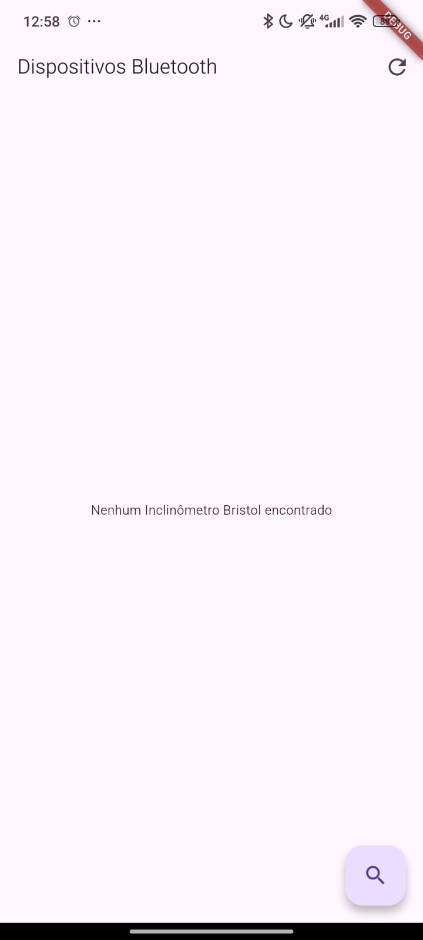
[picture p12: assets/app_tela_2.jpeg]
   

<sup>Fonte: Material produzido pelos autores (2025)</sup>

</div>

<div align="center">

<sub>Figura X - Tela 3 da versão inicial do app do Inclinômetro Bristol </sub>

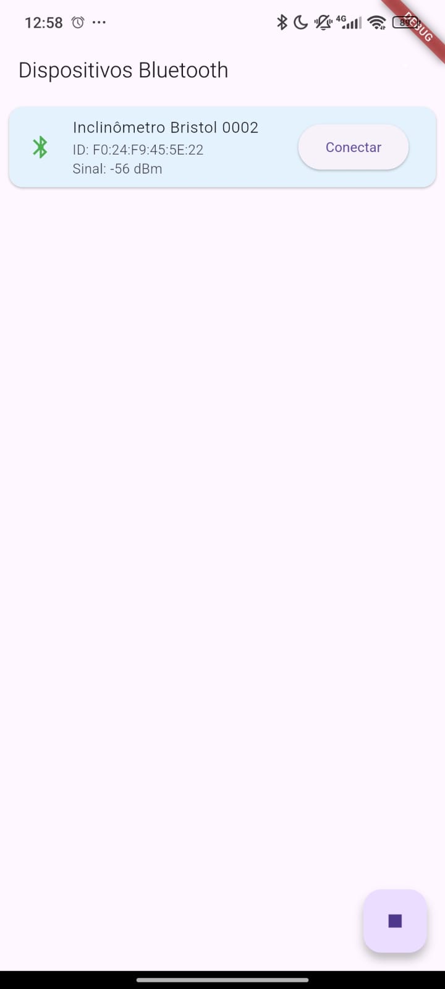
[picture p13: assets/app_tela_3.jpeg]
   

<sup>Fonte: Material produzido pelos autores (2025)</sup>

</div>

<div align="center">

<sub>Figura X - Tela 4 da versão inicial do app do Inclinômetro Bristol </sub>

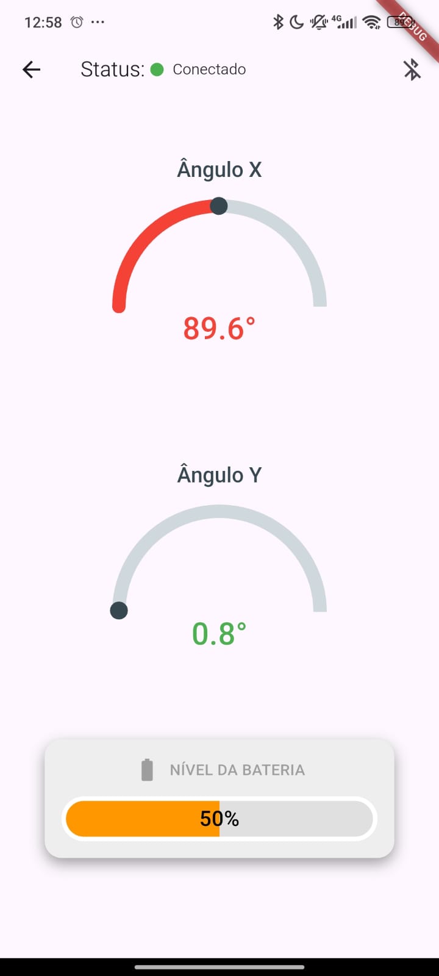
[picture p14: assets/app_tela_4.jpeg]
   

<sup>Fonte: Material produzido pelos autores (2025)</sup>

</div>

&emsp;Por fim, os próximos passos para o próximo (terceiro) mês de desenvolvimento do projeto estará focado em implementar atualizações de firmware de maneira remota.

### 6.4. Terceiro mês de execução do projeto
&emsp;Antes de iniciar o terceiro mês do projeto, foi feita uma reunião com os principais stakeholders e foi definido que a prioridade de desenvolvimento deveria estar na placa de circuito e não nas atualizações de firmware remotas. Essa decisão foi tomada porque o processo de desenvolver placas de circuito, principalmente as mais complexas, é um processo iterativo no qual é comum cometer erros e só perceber uma vez que a placa está pronta. Assim, caso fosse desenvolvida uma placa que precisasse de ajustes, ainda haveria tempo para corrigir isso dentro do escopo de 5 meses de projeto. Dessa forma, esta seção irá tratar exclusivamente do desenvolvimento de uma placa de circuito industrial para acomodar o Inclinômetro Bristol.

#### 6.4.1. Escolha de componentes
&emsp;Para uma placa de circuito industrial e comercializável, entende-se que não é viável utilizar os componentes como eles estavam nas placas anteriores porque eles vinham em versões de módulos prontos, tornando-os mais caros e não viáveis em produtos de mercado. Dessa forma, foi feito um estudo afim de utilizar os CIs (circuitos-integrados) e chips ao invés de utilizar os módulos. Um exemplo disso é o microcontrolador. Nas primeiras versões, utilizou-se um módulo ESP32-Wroom (figura X abaixo), que é um módulo embarcado com um ESP32. O valor desse módulo chegava a custar entre 50 e 70 reais. Na versão industrial da placa de circuito, foi utilizado apenas o chip do ESP32-S3-MINI-N8 (figura X abaixo), que é muito similar ao utilizado anteriormente porém, somando todo o circuito extra para seu funcionamento, não ultrapassa os 30 reais. Seu datasheet pode ser encontrado em: https://br.mouser.com/datasheet/2/891/esp32_s3_mini_1_mini_1u_datasheet_en-2997643.pdf

<div align="center">
<sub>Figura X - Módulo ESP32-Wroom </sub>

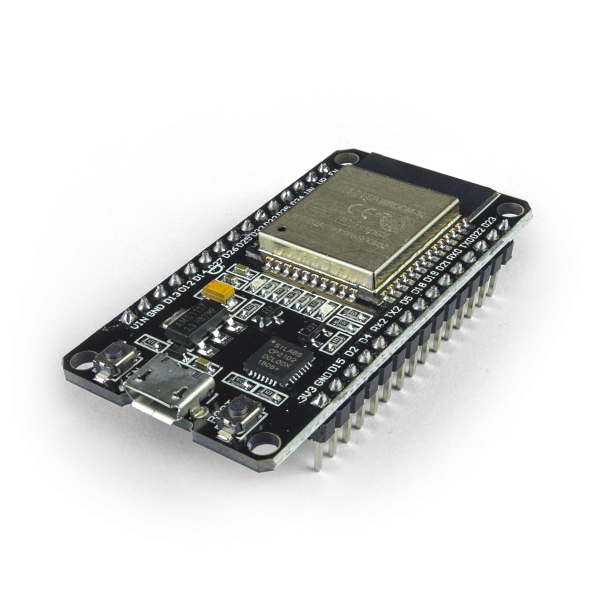
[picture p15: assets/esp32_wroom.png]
   

<sup>Fonte: Material produzido pelos autores (2025)</sup>

</div>

<div align="center">
<sub>Figura X - Chip ESP32-S3-MINI-N8 </sub>

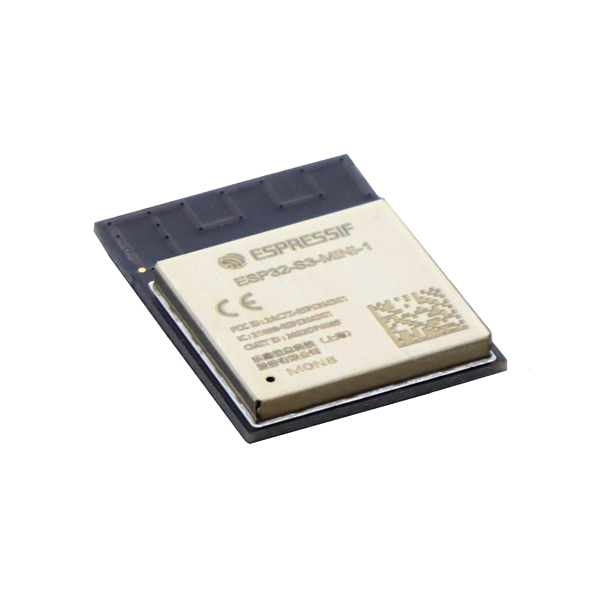
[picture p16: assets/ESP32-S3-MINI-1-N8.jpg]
   

<sup>Fonte: Material produzido pelos autores (2025)</sup>

</div>

&emsp;Além do microcontrolador, foram escolhidos os seguintes CIs/chips:
* CI do MPU9250: Ao invés de utilizar um módulo pronto, o projeto seguiu utilizando apenas o CI, que é extremamente menor do que o módulo. Seu datasheet pode ser encontrado em: https://invensense.tdk.com/download-pdf/mpu-9250-datasheet/. Neste datasheet, é possível ver o circuito mínimo para que o sensor funcione. Tal circuito, considerando a comunicação I2C com o ESP32, pode ser feito com apenas 3 capacitores. Ou seja, é um sensor muito simples de ser utilizado.
* CI do MAX1704X: Ao invés de utilizar um módulo com o MAX17043, que é o responsável por medir a carga da bateria, seguimos também com o seu CI. Seu funcionamento básico está descrito no seguinte datasheet: https://www.analog.com/media/en/technical-documentation/data-sheets/max17043-max17044.pdf. Assim como o MPU, este CI não possui um funcionamento muito complexo. Entretanto, adianto aqui que na versão final da placa, foi utilizado o módulo, uma vez que o CI não estava disponível para compra.
* TP4056: Ao invés de utilizar um módulo baseado no CI, foi decidido criar o próprio circuito de carregamento de baterias utilizando o TP4056, com datasheet em: https://dlnmh9ip6v2uc.cloudfront.net/datasheets/Prototyping/TP4056.pdf. Seu circuito de funcionamente é ligeiramente maior, porém não é complexo. Junto a ele, utilizou-se um CI DW01A e um FS8205 para adicionar proteção à bateria. 
* Demais componentes envolvem conectores micro-usb, um circuito de diodos D3V3XA4B10LP para proteger a porta micro-usb de programação do ESP32, um regulador baixa-queda TLV75801PDRV (regula 5V do usb para 3V3 de funcionamento do ESP32). Além disso, o circuito conta com alguns componentes como leds, botões e resistores gerais para funcionamentos e indicações e também um conjunto de 6 pinos para conectar o módulo do cartão SD. Mais detalhes podem ser visualizados no esquemático da placa, que pode ser acessado no software Kicad. O esquemático se encontra na pasta src/PCI_COMPLETA_1.0/PCI_COMPLETA_1.0.kicad_sch. 

<div align="center">
<sub>Figura X - Esquemático PCI industrial </sub>

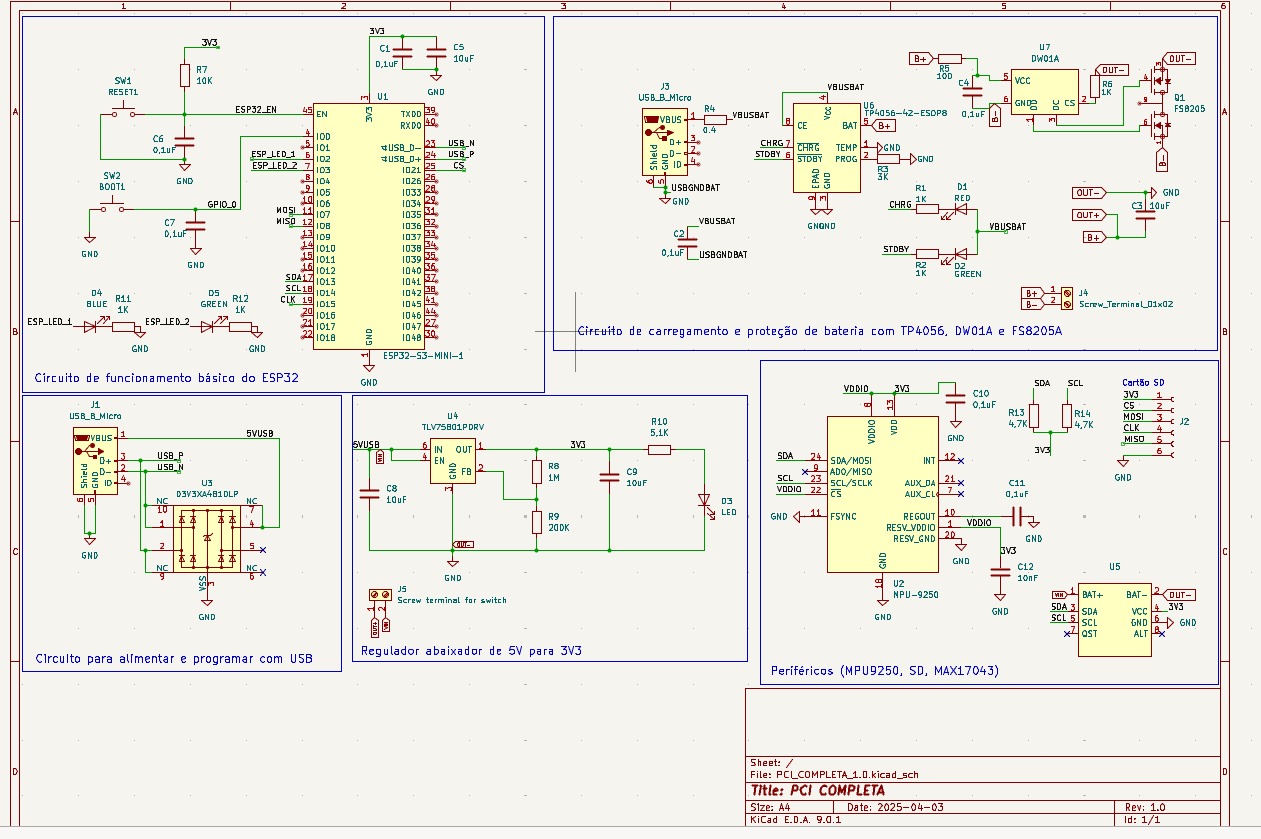
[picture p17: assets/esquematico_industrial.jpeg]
   

<sup>Fonte: Material produzido pelos autores (2025)</sup>

</div>

#### 6.4.2. Desenvolvimento do layout da placa de circuito
&emsp;Não é viável discorrer muito sobre como os componentes da placa de circuito foram arranjados. Entretanto, alguns apontamentos aqui ficam:
* Foram utilizadas 4 camadas, sendo duas para trilhas de sinal e alimentação, uma para 3V3 e outra para GND. Além disso, o plano de GND foi adicionado em todas as camadas a fim de melhorar a dissipação de calor.
* O roteamento das trilhas foi feito de modo a tentar minimizar o tamanho da placa porém sem dificultar o processo com um espaço muito pequeno.
* A antena do chip do ESP32 deve estar para fora da placa para evitar interferências
* As trilhas D+ e D-, para programar o ESP32, foram roteadas como para diferencial a fim de minimizar problemas causados por impedância nas trilhas.
* Várias vias do plano GND foram adicionadas à placa para ajudar a conectar todos os GND e ajudar a dissipar calor. 
* O MPU9250 foi posicionado próximo ao centro da placa para ajudar nas medições de ângulo. 

<div align="center">
<sub>Figura X - Layout PCI industrial </sub>

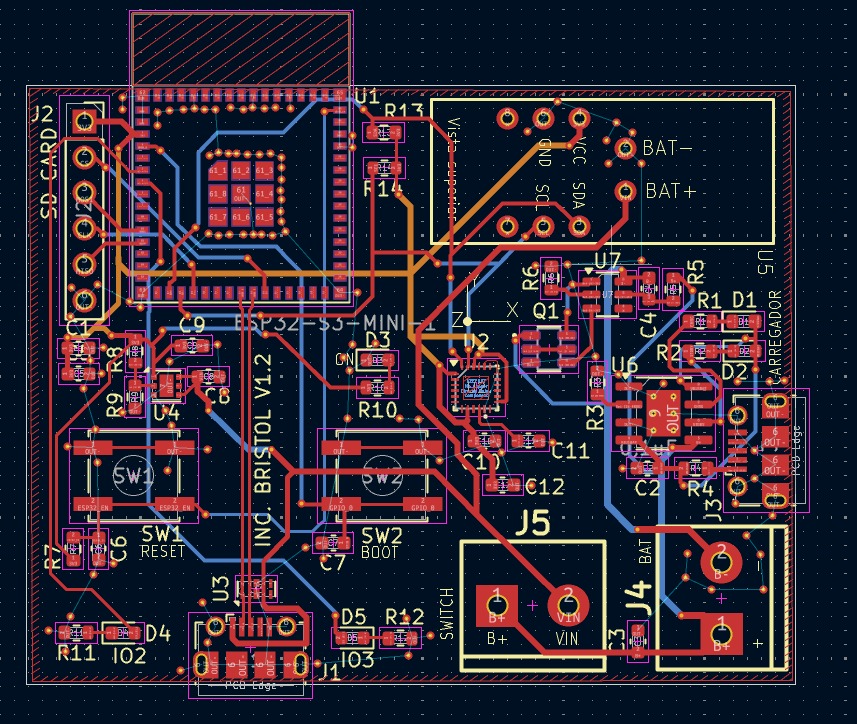
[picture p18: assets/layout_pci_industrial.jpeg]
   

<sup>Fonte: Material produzido pelos autores (2025)</sup>

</div>

&emsp;Com a placa pronta, foram gerados os arquivos de fabricação. Aqui, foram utilizados os serviços da [JLC PCB](https://jlcpcb.com/), que possui um serviço tanto para fazer as placas como para soldar e montar os componentes. Assim, foi gasto um valor total de aproximadamente R$2000 para receber 5 placas, sendo que 2 delas estavam com componentes soldados e realmente utilizáveis. Ou seja, tivemos uma média de 1000 reais por placa desenvolvida após pagar taxas de importação, frete, compra de componentes, etc. 

#### 6.4.3. Testes da placa de circuito
&emsp;Com as placas em mãos, chegou o momento de as testar. Os testes envolvem alimentação da placa, verificar se todos os periféricos funcionam e se o bluetooth também funciona corretamente. Após realizar os testes os resultados foram os seguintes:
* A placa 1 possuía tudo funcionando corretamente, exceto pelo cartão SD, que não era reconhecido.
* A placa 2 possuía tudo funcionando corretamente, incluindo o cartão SD. Algo que indica que o problema na placa 1 não foi de design da placa, mas sim provavelmente alguma solda ruim feita na fábrica. 

&emsp;Após alguns testes, alguns ocorreram algumas infelicidades:
* A placa 2, que possuía tudo funcionando, não estava mais sendo reconhecida pelo computador para ser programada.
* Tivemos que utilizar, então, a placa 1, que não possui cartão SD funcionando.
* Além disso, o módulo de sensor de carga de bateria que possuía ficou danificado após tanto soldá-lo e dessoldar. Dessa forma, a placa ficou, basicamente, com o ESP32 e o MPU9250 funcionando. Está longe de ser um produto final ideal, mas será mais do que suficiente para prosseguir com o projeto.

&emsp;Assim foi finalizado o terceiro mês de projeto. Agora, possuindo uma placa de circuito de nível industrial e que pode ser comercializada como um produto para o mercado, o foco está em realizar polimentos no firmware, adicionar atualizações remotas e melhorar o aplicativo mobile. Tudo isso será feito no quarto e quinto mês de projeto. 

## 7. Simulação do protótipo e casos de teste
&emsp;Em um projeto que envolve hardware e software, é comum que o desenvolvimento da solução passe por 3 etapas:
* Simulação, a fim de entender se a ideia é viável, se os componentes eletrônicos interagem bem entre si, validar ideias de código sem se preocupar com componentes físicos;
* Prototipação em protoboard, de modo que as conexões não sejam definitivas e o produto possa ser testado sem muito compromisso. Aqui, os componentes são testados levando em consideração o modo como eles funcionam no mundo real. Ou seja, a solução é validada no mundo real;
* Prototipação de placa de circuito, sendo normalmente o último estágio de desenvolvimento, quando já se sabe que a solução está relativamente pronta e não deve sofrer grandes alterações. É uma versão mais robusta e profissional do produto;

&emsp;Para as primeiras duas semanas de desenvolvimento do projeto, o foco estará em realizar a simulação do projeto em um software denominado [Wokwi](https://wokwi.com/). De acordo com a documentação oficial, o Wokwi é uma plataforma de simulação eletrônica online e gratuita, que permite simular o uso de diversos componentes eletrônicos em conjunto com microcontroladores como o ESP32 e o Arduino. A finalidade de se utilizar essa ferramenta está na necessidade de testar o hardware e os componentes eletrônicos em conjunto com toda a programação antes de iniciar de fato a montagem física do circuito. Abaixo, estará documentado o processo de desenvolvimento da simulação bem como os casos de testes para validar que o projeto funciona em ambiente simulado atendendo aos requisitos funcionais e não-funcionais. 

**Funcionamento da simulação:**<br>
A simulação no Wokwi replica o circuito físico do protótipo usando:
- **ESP32**: Microcontrolador responsável pela leitura dos sensores e processamento.
- **MPU6050**: Simula o acelerômetro/giroscópio para medição de inclinação.
- **Terminal Serial**: Exibe os valores de pitch e roll em tempo real.
- **Filtro de Kalman**: Combina dados do acelerômetro (ângulo absoluto) e giroscópio (taxa de variação) para suavizar ruídos.

O código simulado:
1. Lê dados brutos do MPU6050 (aceleração e giroscópio).
2. Calcula ângulos brutos via acelerômetro (pitch/roll).
3. Aplica o filtro de Kalman para reduzir oscilações.

**Casos de Teste para Validação**

<div align="center">

| **TC#** | **Descrição** | **Entrada/Situação** | **Resultado Esperado** | **Método de Validação** |
|---|---|---|---|---|
| TC01 | Medição em superfície plana | Ax = 0, Ay = 0, Az = 9.81 m/s² | Pitch ≈ 0°, Roll ≈ 0° (±1°) | Verificar no terminal serial. |
| TC02 | Inclinação de 45° no Roll | Ax = 0g, Ay = 0.75, Az = 0.75g | Roll ≈ 45° (±1°), Pitch ≈ 0° | Comparar com `atan2(Ay, Az)`. |
| TC03 | Inclinação de 45° no Pitch | Ax = 0.75, Ay = 0g, Az = 0.75g | Pitch ≈ 45° (±1°), Roll ≈ 0° | Comparar com `atan2(-Ax, Az)`. |
| TC04 | Inclinação combinada (30° Pitch + 30° Roll) | Ax = 0.5g, Ay = 0.5g, Az = 0.707g | Pitch ≈ 30°, Roll ≈ 30° (não linear) | Validar com `θ = arccos(Az) ≈ 30°`. |
| TC05 | Vibração simulada (ruído ±0.2g) | Adicionar ruído aos eixos X/Y | Oscilação < ±2° após filtro | Analisar gráfico no serial plotter. |
| TC06 | Movimento brusco (0° → 45° em 1s) | Alterar Ax de 0g para 0.5g abruptamente | Convergência em < 1s | Medir tempo de estabilização. |

</div>

<p align="center">
<sub>Quadro 8: Casos de teste para a simulação -  Material criado e desenvolvido pelo desenvolvedor.</sub><br>
</p>

&emsp;Após realizar os testes com os devidos inputs no simulador Wokwi, foi constatado que:
* TC01: passa no teste com êxito
* TC02: passa no teste com êxito
* TC03: passa no teste com êxito
* TC04: passa no teste com êxito
* TC05: Não é possível testar no simulador 
* TC06: passa no teste com algumas ressalvas (em alguns casos, demora alguns segundos para estabilizar as últimas casas decimais)

&emsp;A partir disso, podemos concluir que a simulação foi feita com sucesso e praticamente todos os seus casos de teste passaram com êxito, validando, assim, a ideia da construção do Inclinômetro Bristol. A partir disso, o próximo passo do projeto é montar o hardware da solução e testar fisicamente. Felizmente, por conta da simulação, o firmware/código básico para testes já está pronto. 

&emsp;O link para a simulação pode ser encontrado aqui: https://wokwi.com/projects/421158430038353921

<div align="center">

<sub>Figura 4 - Simulação do protótipo no Wokwi </sub>

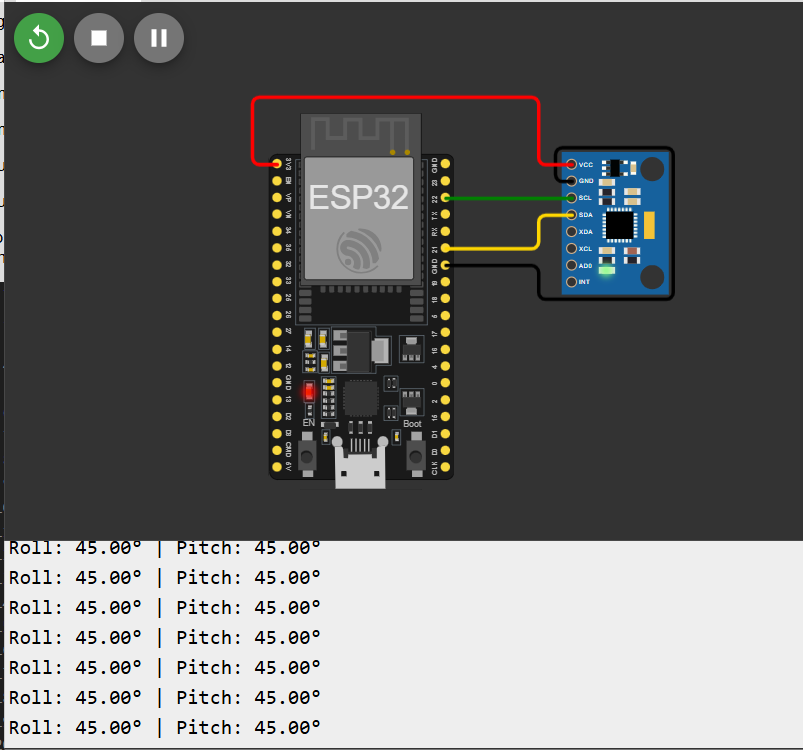
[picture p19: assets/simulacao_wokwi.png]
   

<sup>Fonte: Material produzido pelos autores (2025)</sup>

</div>

## X. Referências
MARÍAS, Julián. Persona. Alianza, 1997. Disponível em: http://www.hottopos.com/mp2/mariaspers.htm. Acesso em: 22 jan. 2025.

GORNY, L. The story of storyboarding: exploring the hidden art form behind films. Disponível em: <https://www.itsnicethat.com/features/the-story-of-storyboarding-animation-film-061021>. Acesso em 23 jan. 2025

ARIELE. O que é ISO? Blog da Qualidade. Disponível em: https://blogdaqualidade.com.br/o-que-e-iso/. Acesso em: 25 jan. 2025.

BRITTON, J. What Is ISO 25010? Disponível em: <https://www.perforce.com/blog/qac/what-is-iso-25010>. Acesso em: 25 jan. 2025.

‌

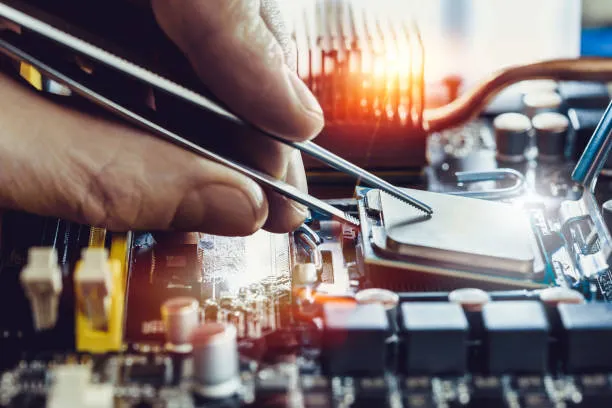
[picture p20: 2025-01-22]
assets/placeholder.webp

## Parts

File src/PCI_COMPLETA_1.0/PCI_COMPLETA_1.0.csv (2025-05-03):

Reference | Value | Footprint | Datasheet | Qty | DNP | Exclude from BOM | Exclude from Board
C1,C2,C4,C6,C7,C10,C11 | 0,1uF | Capacitor_SMD:C_0805_2012Metric_Pad1.18x1.45mm_HandSolder | ~ | 7
C3,C5,C8,C9 | 10uF | Capacitor_SMD:C_0805_2012Metric_Pad1.18x1.45mm_HandSolder | ~ | 4
C12,C13 | 10nF | Capacitor_SMD:C_0805_2012Metric_Pad1.18x1.45mm_HandSolder | ~ | 2
C14 | 1uF | Capacitor_SMD:C_0805_2012Metric_Pad1.18x1.45mm_HandSolder | ~ | 1
D1 | RED | LED_SMD:LED_0805_2012Metric | ~ | 1
D2,D5 | GREEN | LED_SMD:LED_0805_2012Metric | ~ | 2
D3 | LED | LED_SMD:LED_0805_2012Metric | ~ | 1
D4 | BLUE | LED_SMD:LED_0805_2012Metric | ~ | 1
J1,J3 | USB_B_Micro | Connector_USB:USB_Micro-B_Amphenol_10104110_Horizontal | ~ | 2
J2 | Conn_01x06_Socket | Connector_PinSocket_2.54mm:PinSocket_1x06_P2.54mm_Vertical | ~ | 1
J4 | Screw_Terminal_01x02 | mod_conn_screw:mors_2p | ~ | 1
J5 | Screw terminal for switch | mod_conn_screw:mors_2p | ~ | 1
Q1 | FS8205A | FS8205A:SOP65P640X120-8N |  | 1
R1,R2,R6,R11,R12,R16 | 1K | Resistor_SMD:R_0805_2012Metric_Pad1.20x1.40mm_HandSolder | ~ | 6
R3 | 3K | Resistor_SMD:R_0805_2012Metric_Pad1.20x1.40mm_HandSolder | ~ | 1
R4 | 0.4 | Resistor_SMD:R_0805_2012Metric_Pad1.20x1.40mm_HandSolder | ~ | 1
R5 | 100 | Resistor_SMD:R_0805_2012Metric_Pad1.20x1.40mm_HandSolder | ~ | 1
R7 | 10K | Resistor_SMD:R_0805_2012Metric_Pad1.20x1.40mm_HandSolder | ~ | 1
R8 | 1M | Resistor_SMD:R_0805_2012Metric_Pad1.20x1.40mm_HandSolder | ~ | 1
R9 | 200K | Resistor_SMD:R_0805_2012Metric_Pad1.20x1.40mm_HandSolder | ~ | 1
R10 | 5,1K | Resistor_SMD:R_0805_2012Metric_Pad1.20x1.40mm_HandSolder | ~ | 1
R13,R14 | 4,7K | Resistor_SMD:R_0805_2012Metric_Pad1.20x1.40mm_HandSolder | ~ | 2
R15 | 150 | Resistor_SMD:R_0805_2012Metric_Pad1.20x1.40mm_HandSolder | ~ | 1
SW1 | RESET1 | Button_Switch_SMD:SW_Push_1P1T_NO_CK_KSC6xxJ | ~ | 1
SW2 | BOOT1 | Button_Switch_SMD:SW_Push_1P1T_NO_CK_KSC6xxJ | ~ | 1
U1 | ESP32-S3-MINI-1 | RF_Module:ESP32-S2-MINI-1 | https://www.espressif.com/sites/default/files/documentation/esp32-s3-mini-1_mini-1u_datasheet_en.pdf | 1
U2 | MPU-9250 | Sensor_Motion:InvenSense_QFN-24_3x3mm_P0.4mm | https://invensense.tdk.com/wp-content/uploads/2015/02/PS-MPU-9250A-01-v1.1.pdf | 1
U3 | D3V3XA4B10LP | Package_DFN_QFN:Diodes_UDFN-10_1.0x2.5mm_P0.5mm | https://www.diodes.com/assets/Datasheets/D3V3XA4B10LP.pdf | 1
U4 | TLV75801PDRV | Package_SON:WSON-6-1EP_2x2mm_P0.65mm_EP1x1.6mm | https://www.ti.com/lit/ds/symlink/tlv758p.pdf | 1
U5 | MAX17043G | Package_DFN_QFN:TDFN-8-1EP_3x2mm_P0.5mm_EP1.80x1.65mm | https://www.analog.com/media/en/technical-documentation/data-sheets/max17043-max17044.pdf | 1
U6 | TP4056-42-ESOP8 | Package_SO:SOIC-8-1EP_3.9x4.9mm_P1.27mm_EP2.41x3.3mm_ThermalVias | https://www.lcsc.com/datasheet/lcsc_datasheet_2410121619_TOPPOWER-Nanjing-Extension-Microelectronics-TP4056-42-ESOP8_C16581.pdf | 1
U7 | DW01A | Package_TO_SOT_SMD:SOT-23-6 | https://hmsemi.com/downfile/DW01A.PDF | 1

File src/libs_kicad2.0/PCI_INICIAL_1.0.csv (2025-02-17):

Reference | Value | Datasheet | Footprint | Qty | DNP
C1,C2 | 104 100nF | ~ | Capacitor_THT:C_Disc_D3.0mm_W1.6mm_P2.50mm | 2
C3,C4 | 10uF 16V | ~ | Capacitor_THT:C_Radial_D4.0mm_H5.0mm_P1.50mm | 2
U1 | ~ |  | ESP32-Wroom-32-Module-lib:ESP32-Wroom-32-Module | 1

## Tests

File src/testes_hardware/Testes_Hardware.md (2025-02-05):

# Testes de hardware

&emsp;Nesta pasta, estão dispostos códigos para teste inicial dos componentes físicos programáveis utilizados no projeto. A ideia é ter um "Hello World" para cada sensor, de modo a agilizar o processo de se testar componentes novos.

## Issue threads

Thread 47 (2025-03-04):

Aprimoramento de firmware

caio-alcantara, 2025-03-04:
Descrição: Implementar funcionalidades de monitoramento de bateria, armazenamento de dados e otimização de cálculos.

Tarefas Granulares:
* Integrar biblioteca MAX17043 para monitorar nível da bateria (RF03, RNF02).
* Desenvolver rotina de salvamento de dados no cartão SD (RF04, RNF05).
* Otimizar parâmetros do filtro de Kalman para reduzir ruído (RNF04).
* Adicionar LED indicador de status da conexão Bluetooth (RF06).

Closed 2025-03-24.

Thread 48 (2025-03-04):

Redesenhar PCI

caio-alcantara, 2025-03-04:
Descrição: Otimizar layout para resistência a vibração, proteção contra ruído e inclusão de novos componentes. Será necessário fazer outra placa para, além de conter os novos componentes, ser utilizada no lugar da placa que será enviada para a Bristol

Tarefas Granulares:
* Incluir módulo MAX17043 e slot Micro SD diretamente na PCB (RNF02).
* Corrigir posicionamento de entrada da bateria.
* Testar montagem "SMD" do MPU9250

Closed 2025-03-24.

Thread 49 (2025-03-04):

Desenvolver interface gráfica básica (mobile/flutter)

caio-alcantara, 2025-03-04:
Descrição: criar uma interface básica para dispositivos móveis utilizando Flutter. A interface deve possibilitar escanear e conectar no inclinômetro. Após isso, deve ser possível ver as medidas de ângulo e status de carga da bateria

Closed 2025-03-24.

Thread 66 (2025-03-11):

Criar simbolos e footprints para nova pci

caio-alcantara, 2025-03-11:
Será necessário criar simbolos e footprints para o módulo detector de carga de bateria/módulo cartão sd e aprimorar o footprint do tp4056. Além disso, desenvolver um footprint smd para o mpu9250 para testar

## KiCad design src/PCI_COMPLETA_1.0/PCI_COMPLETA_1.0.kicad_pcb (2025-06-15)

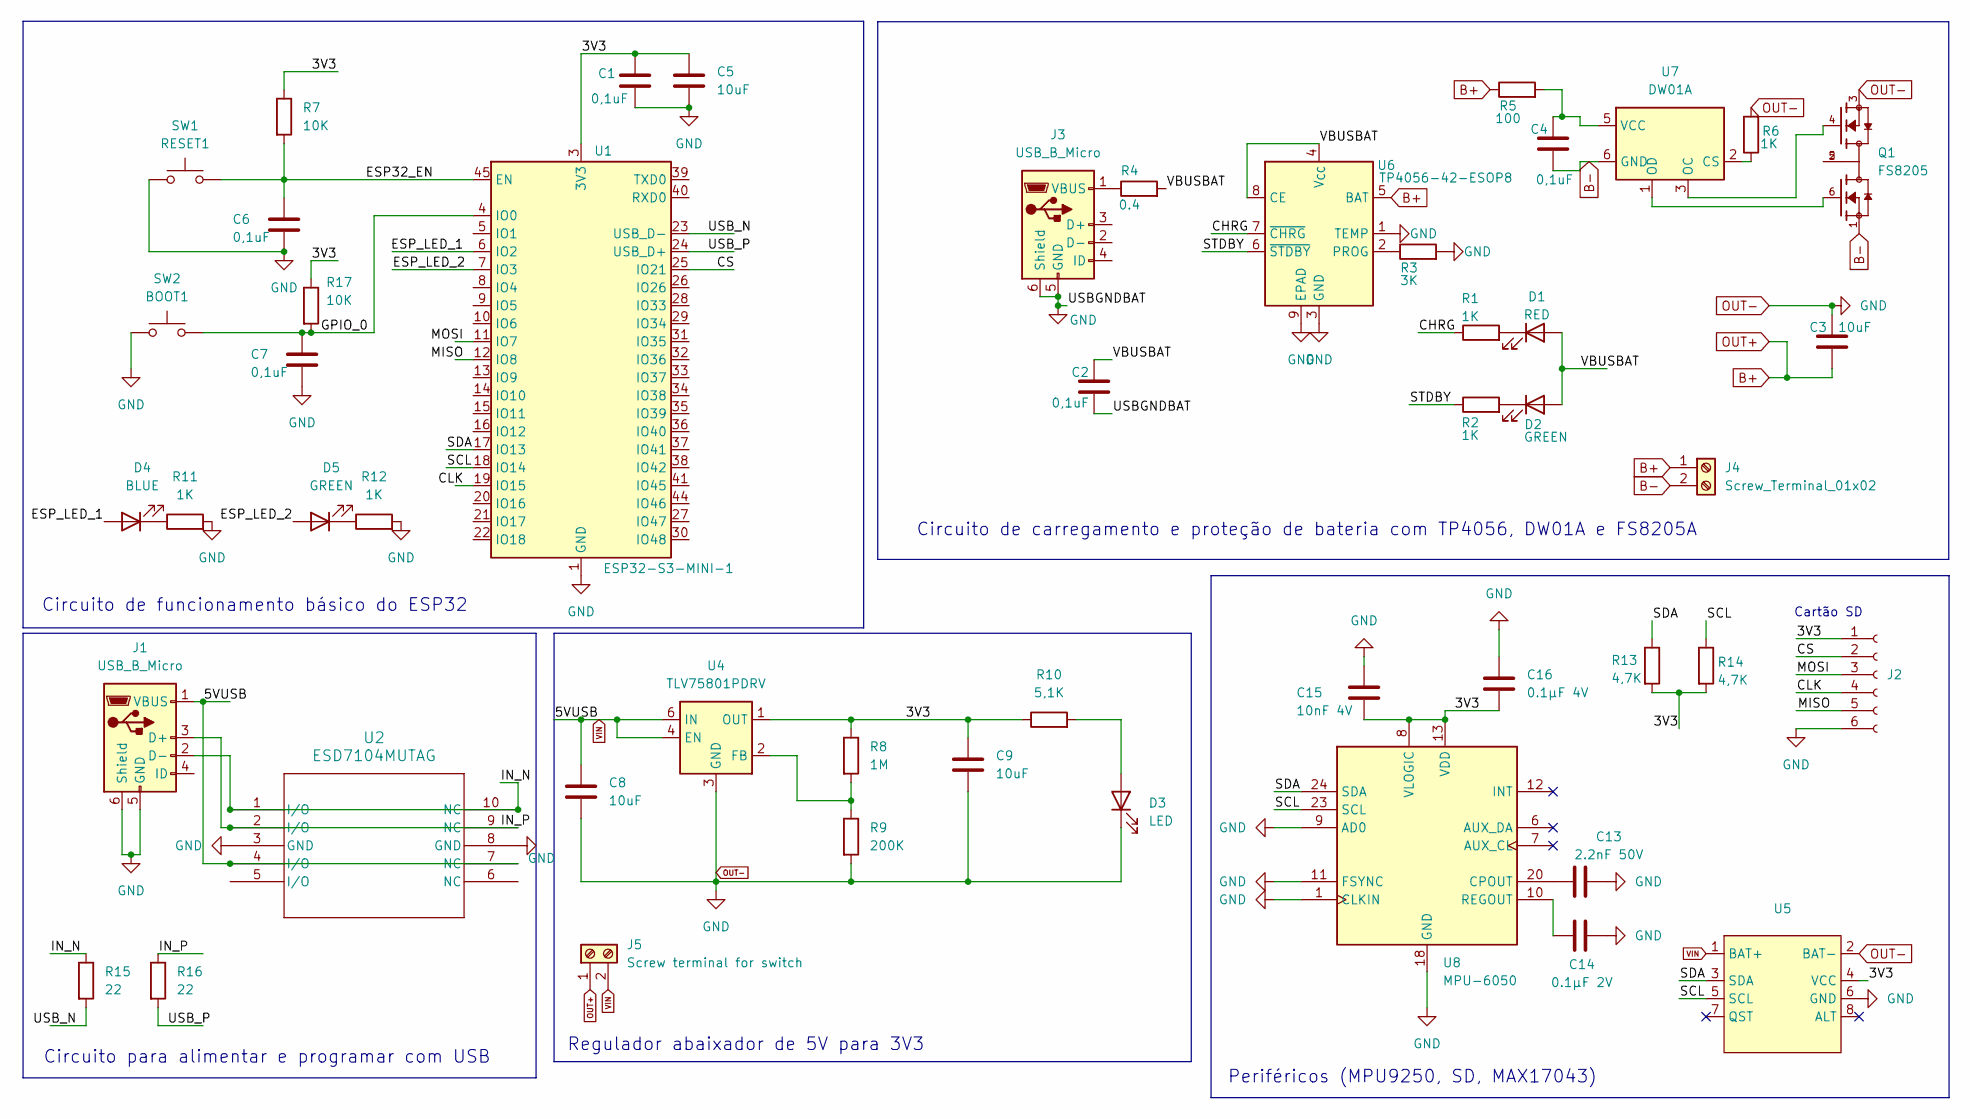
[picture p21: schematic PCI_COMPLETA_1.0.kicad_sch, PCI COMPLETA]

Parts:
C1, C2, C4, C6, C7: 0,1uF; C_0603_1608Metric
C3, C5, C8, C9: 10uF; C_0603_1608Metric
C13: 2.2nF 50V; C_0603_1608Metric
C14: 0.1µF 2V; C_0603_1608Metric
C15: 10nF 4V; C_0603_1608Metric
C16: 0.1µF 4V; C_0603_1608Metric
D1: RED; LED_0603_1608Metric
D2, D5: GREEN; LED_0603_1608Metric
D3: LED; LED_0603_1608Metric
D4: BLUE; LED_0603_1608Metric
J1, J3: USB_B_Micro; USB_Micro-B_Molex-105017-0001
J2: Conn_01x06_Socket; PinSocket_1x06_P2.54mm_Vertical
J4: Screw_Terminal_01x02; mors_2p
J5: Screw terminal for switch; mors_2p
Q1: FS8205; SOT95P280X145-6N; PARTREV 1.9
R1, R2, R6, R11, R12: 1K; R_0603_1608Metric
R3: 3K; R_0603_1608Metric
R4: 0.4; R_0603_1608Metric
R5: 100; R_0603_1608Metric
R7, R17: 10K; R_0603_1608Metric
R8: 1M; R_0603_1608Metric
R9: 200K; R_0603_1608Metric
R10: 5,1K; R_0603_1608Metric
R13, R14: 4,7K; R_0603_1608Metric
R15, R16: 22; R_0402_1005Metric
SW1: RESET1; SW_Push_1P1T_NO_CK_KSC6xxJ
SW2: BOOT1; SW_Push_1P1T_NO_CK_KSC6xxJ
U1: ESP32-S3-MINI-1; XCVR_ESP32-S3-MINI-1-N8
U2: ESD7104MUTAG; UDFN10_ONS
U4: TLV75801PDRV; WSON-6-1EP_2x2mm_P0.65mm_EP1x1.6mm
U5: MAX
U6: TP4056-42-ESOP8; SOIC-8-1EP_3.9x4.9mm_P1.27mm_EP2.41x3.3mm_ThermalVias
U7: DW01A; SOT-23-6
U8: MPU-6050; InvenSense_QFN-24_4x4mm_P0.5mm

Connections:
/3V3: C1.1, C5.1, C9.1, C15.2, C16.2, J2.1, R7.1, R8.1, R10.1, R13.2, R14.2, R17.1, U1.3 (3V3), U4.1 (OUT), U5.4 (VCC), U8.8 (VLOGIC), U8.13 (VDD)
/CHRG: R1.1, U6.7 (~CHRG)
/CLK: J2.4, U1.19 (IO15)
/CS: J2.2, U1.25 (IO21)
/ESP32_EN: C6.1, R7.2, SW1.2, U1.45 (EN)
/ESP_LED_1: D4.2 (A), U1.6 (IO2)
/ESP_LED_2: D5.2 (A), U1.7 (IO3)
/GPIO_0: C7.1, R17.2, SW2.2, U1.4 (IO0)
/IN_N: J1.2 (D-), R15.1, U2.1 (I/O), U2.10 (NC)
/IN_P: J1.3 (D+), R16.1, U2.2 (I/O), U2.9 (NC)
/MISO: J2.5, U1.12 (IO8)
/MOSI: J2.3, U1.11 (IO7)
/SCL: R14.1, U1.18 (IO14), U5.5 (SCL), U8.23 (SCL)
/SDA: R13.1, U1.17 (IO13), U5.3 (SDA), U8.24 (SDA)
/STDBY: R2.1, U6.6 (~STDBY)
/USB_N: R15.2, U1.23 (USB_D-)
/USB_P: R16.2, U1.24 (USB_D+)
/VBUSBAT: C2.1, D1.2 (A), D2.2 (A), R4.2, U6.4 (V_{CC}), U6.8 (CE)
B+: C3.2, J4.1, J5.1, R5.1, U6.5 (BAT)
B-: C4.2, J4.2, Q1.1, U7.6 (GND)
unnamed: D1.1 (K), R1.2
unnamed: D2.1 (K), R2.2
unnamed: D3.2 (A), R10.2
unnamed: D4.1 (K), R11.1
unnamed: D5.1 (K), R12.1
unnamed: J3.1 (VBUS), R4.1
unnamed: Q1.2, Q1.5
unnamed: R8.2, R9.1, U4.2 (FB)
unnamed: R3.1, U6.2 (PROG)
unnamed: R6.1, U7.2 (CS)
unnamed: Q1.4, U7.3 (OC)
unnamed: Q1.6, U7.1 (OD)
unnamed: C4.1, R5.2, U7.5 (VCC)
unnamed: C13.2, U8.20 (CPOUT)
unnamed: C14.2, U8.10 (REGOUT)
OUT-: C1.2, C2.2, C3.1, C5.2, C6.2, C7.2, C8.2, C9.2, C13.1, C14.1, C15.1, C16.1, D3.1 (K), J1.5 (GND), J1.6 (Shield), J2.6, J3.5 (GND), J3.6 (Shield), Q1.3, R3.2, R6.2, R9.2, R11.2, R12.2, SW1.1, SW2.1, U1.1 (GND), U1.2 (GND), U1.42 (GND), U1.43 (GND), U1.46 (GND), U1.47 (GND), U1.48 (GND), U1.49 (GND), U1.50 (GND), U1.51 (GND), U1.52 (GND), U1.53 (GND), U1.54 (GND), U1.55 (GND), U1.56 (GND), U1.57 (GND), U1.58 (GND), U1.59 (GND), U1.60 (GND), U1.61 (GND), U1.62 (GND), U1.63 (GND), U1.64 (GND), U1.65 (GND), U2.3 (GND), U2.8 (GND), U4.3 (GND), U4.7 (GND), U5.2 (BAT-), U5.6 (GND), U6.1 (TEMP), U6.3 (GND), U6.9 (EPAD), U8.1 (CLKIN), U8.9 (AD0), U8.11 (FSYNC), U8.18 (GND)
VIN: C8.1, J1.1 (VBUS), J5.2, U2.4 (I/O), U2.7 (NC), U4.4 (EN), U4.6 (IN), U5.1 (BAT+)

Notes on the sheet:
Circuito de funcionamento básico do ESP32
Regulador abaixador de 5V para 3V3
Circuito para alimentar e programar com USB
Cartão SD
Periféricos (MPU9250, SD, MAX17043)
Circuito de carregamento e proteção de bateria com TP4056, DW01A e FS8205A

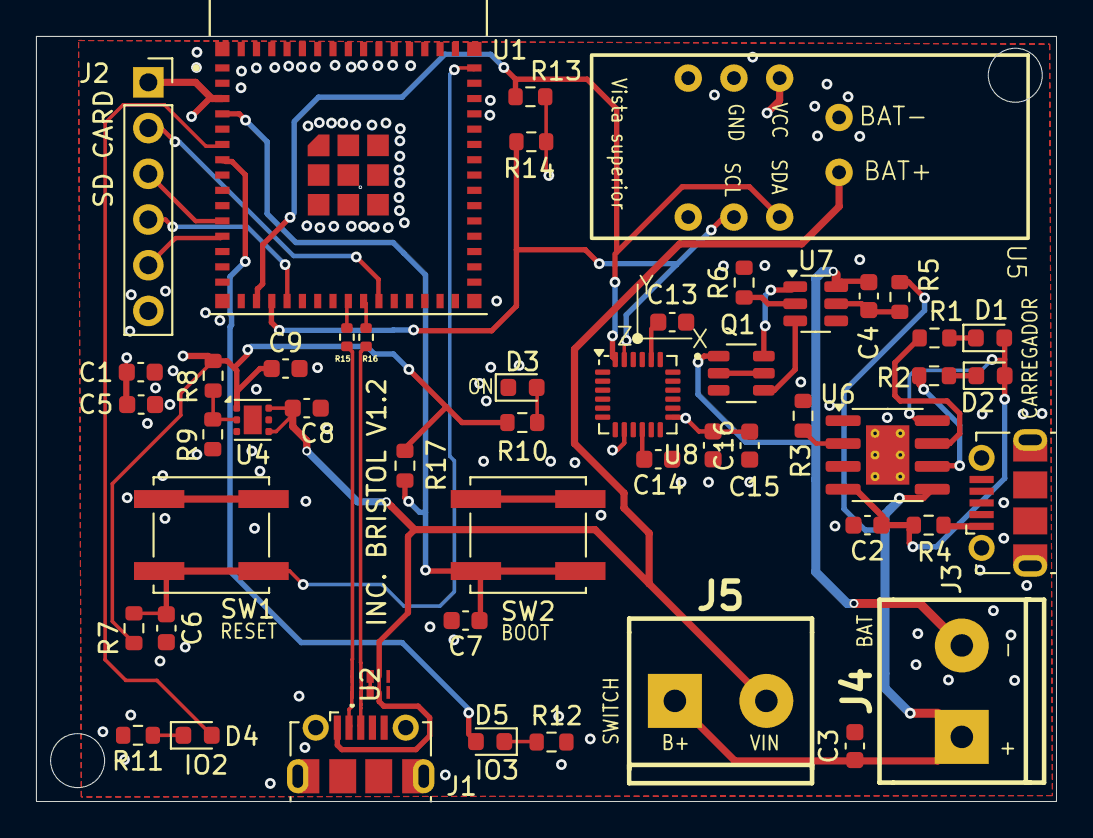
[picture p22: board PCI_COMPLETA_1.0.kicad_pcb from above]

Board: 4 copper layers, 56.7 x 42.5 mm, 50 parts (0 on the bottom side), 37 nets.

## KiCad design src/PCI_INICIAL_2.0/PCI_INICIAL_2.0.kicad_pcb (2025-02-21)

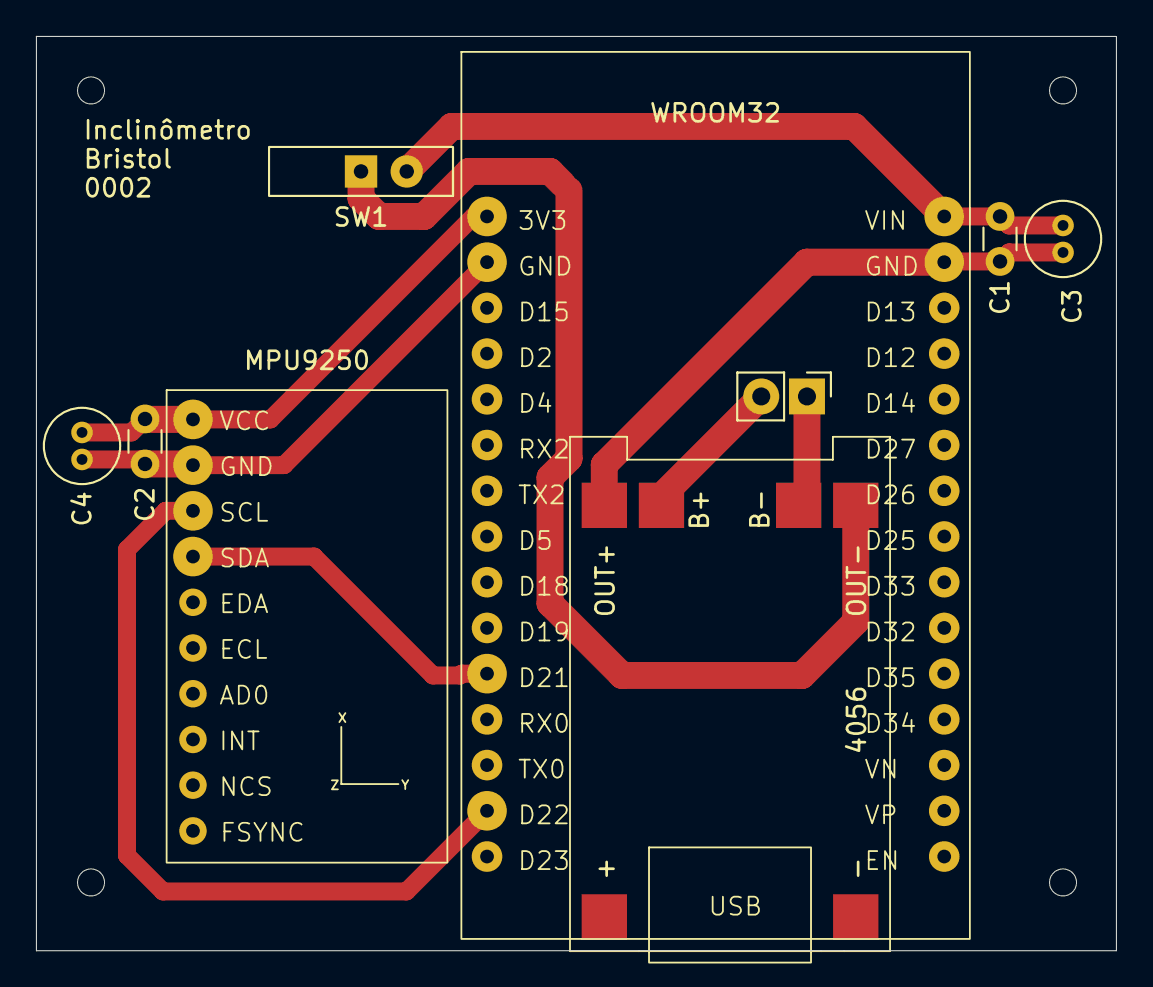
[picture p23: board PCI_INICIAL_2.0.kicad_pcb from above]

Board: 2 copper layers, 60.0 x 50.8 mm, 9 parts (0 on the bottom side), 8 nets.

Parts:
C1, C2: 104 100nF; C_Disc_D3.0mm_W1.6mm_P2.50mm
C3, C4: 10uF 16V; C_Radial_D4.0mm_H5.0mm_P1.50mm
J1: 2 male pin header; PinHeader_1x02_P2.54mm_Vertical
SW1: Switch; SW_Slide-03_Wuerth-WS-SLTV_10x2.5x6.4_P2.54mm
U1: ESP32; ESP32-Wroom-32-Module
U2: MPU9250 Module; MPU9250_Module
U3: TP4056

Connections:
3V3: C2.1, C4.1, U1.1 (3V3), U2.1 (VCC)
B+: J1.2, U3.2 (B+)
B-: J1.1, U3.3 (B-)
GND: C1.2, C2.2, C3.2, C4.2, U1.2 (GND), U1.17 (GND), U2.2 (GND), U3.1 (OUT-)
OUT+: SW1.1, U3.4 (OUT+)
SCL: U1.14 (D22), U2.3 (SCL)
SDA: U1.11 (D21), U2.4 (SDA)
VIN: C1.1, C3.E, SW1.2, U1.16 (VIN)

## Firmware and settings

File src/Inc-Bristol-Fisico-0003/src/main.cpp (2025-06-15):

// ******************* Imports e bibliotecas ******************* //
#include <Arduino.h>
#include <Wire.h>
#include <MPU9250.h>
#include "Config.h"
#include "KalmanFilter.h"
#include "SensorManager.h"
#include "DataProcessor.h"
#include "BluetoothLowEnergy.h"
#include <SparkFun_MAX1704x_Fuel_Gauge_Arduino_Library.h>
#include <SPI.h>
#include <SD.h>
#include "FFat.h"

// ******************* Instanciação de objetos e Variáveis Globais  ******************* //
MPU9250 mpu; // Instância do sensor MPU9250
MPU9250Setting mpu_settings; // Configurações do sensor MPU9250
SensorManager sensor(mpu); // Gerenciador do sensor

SFE_MAX1704X lipo; // Instância do sensor de bateria

KalmanFilter pitch_filter(
    Config::Kalman::PITCH_Q_ANGLE, // Valores definidos no namespace Config
    Config::Kalman::PITCH_Q_BIAS,
    Config::Kalman::PITCH_R_MEASURE
);

KalmanFilter roll_filter(
    Config::Kalman::ROLL_Q_ANGLE,
    Config::Kalman::ROLL_Q_BIAS,
    Config::Kalman::ROLL_R_MEASURE
);

// Utilizado para armazenar o tempo da última atualização
unsigned long last_update = 0;
static unsigned long last_battery_check = 0;
static unsigned long last_sensor_update = 0;

// Preseça de cartão SD
bool sd_present = false;

// ******************* Funções Auxiliáres ******************* //

// Lidar com erros críticos no sensor
// Caso o sensor não seja encontrado no barramento I2C, piscar o led.
// Quando o sensor for encontrado, desligar o led.
void handleSensorError() {
    Serial.println("Erro crítico no sensor! Tentando reconectar...");
    bool mensagemImpressa = true;
    unsigned long previousMillis = 0;
    const unsigned long interval = 100;

    while (true) {
        unsigned long currentMillis = millis();
        if (currentMillis - previousMillis >= interval) {
            previousMillis = currentMillis;
            // Pisca o LED para indicar erro
            digitalWrite(Config::LED_PIN, !digitalRead(Config::LED_PIN));
        }
        if (sensor.initialize()) {
            digitalWrite(Config::LED_PIN, LOW);
            Serial.println("Sensor reconectado!");
            break;
        }
    }
}

void handleBatteryError(){
    Serial.println("Erro crítico na bateria! Tentando reconectar...");
    bool mensagemImpressa = true;
    unsigned long previousMillis = 0;
    const unsigned long interval = 100;

    while (true) {
        unsigned long currentMillis = millis();
        if (currentMillis - previousMillis >= interval) {
            previousMillis = currentMillis;
            // Pisca o LED para indicar erro
            digitalWrite(Config::LED_PIN, !digitalRead(Config::LED_PIN));
        }
        if (lipo.begin()) {
            digitalWrite(Config::LED_PIN, LOW);
            Serial.println("Bateria reconectada!");
            break;
        }
    }
}

// Inicializa os filtros de Kalman para os ângulos de pitch e roll
// Pega o primeiro dado dos sensores e inicializa os filtros com tais valores 
void initializeFilters() {
    const auto data = sensor.getData();
    pitch_filter.initialize(DataProcessor::calculateAccelerometerPitch(
        data.accel.x, data.accel.y, data.accel.z));
    roll_filter.initialize(DataProcessor::calculateAccelerometerRoll(
        data.accel.y, data.accel.z));
}

void storeBatteryData(float batteryPercentage, float batteryVoltage, unsigned long timestamp, bool sd_present) {
    if (sd_present) {
        File batteryFile = SD.open("/battery.csv", FILE_APPEND);
        if (batteryFile) {
            batteryFile.print(batteryPercentage);
            batteryFile.print(",");
            batteryFile.print(batteryVoltage);
            batteryFile.print(",");
            batteryFile.println(timestamp);
            batteryFile.close();
        }
    }
}

void storeInclinationData(float total_inclination, float pitch_inclination, unsigned long timestamp, bool sd_present) {
    if (sd_present) {
        File pitchInclination = SD.open("/pitch_inclination.csv", FILE_APPEND);
        if (pitchInclination) {
            pitchInclination.print(pitch_inclination);
            pitchInclination.print(",");
            pitchInclination.println(timestamp);
            pitchInclination.close();
        }

        File totalInclinationFile = SD.open("/total_inclination.csv", FILE_APPEND);
        if (totalInclinationFile) {
            totalInclinationFile.print(total_inclination);
            totalInclinationFile.print(",");
            totalInclinationFile.println(timestamp);
            totalInclinationFile.close();
        }
    }
}

void setupSDCard() {
    SPI.begin(Config::SD_CLK_PIN, Config::SD_MISO_PIN, Config::SD_MOSI_PIN, Config::SD_CS_PIN);  
    
    if (!SD.begin(Config::SD_CS_PIN)) {
        Serial.println("Falha ao inicializar o cartão SD.");
    } else {
        Serial.println("Cartão SD inicializado com sucesso.");
        sd_present = true;

        // Configuração de arquivos de log

        File totalInclinationFile = SD.open("/total_inclination.csv", FILE_APPEND);
        if (totalInclinationFile) {
            if (totalInclinationFile.size() == 0) {
                totalInclinationFile.println("total_inclination,timestamp");
            }
            totalInclinationFile.close();
        }

        File batteryFile = SD.open("/battery.csv", FILE_APPEND);
        if (batteryFile) {
            if (batteryFile.size() == 0) {
                batteryFile.println("battery,voltage,timestamp");
            }
            batteryFile.close();
        }

        File pitchInclination = SD.open("/pitch_inclination.csv", FILE_APPEND);
        if (pitchInclination) {
            if (pitchInclination.size() == 0) {
                pitchInclination.println("pitch_inclination,timestamp");
            }
            pitchInclination.close();
        }
    }
}


// ******************* Setup ******************* //
void setup() {
    pauseNotifications = false; // Permite notificações BLE
    Serial.begin(Config::SERIAL_BAUD_RATE); // Valores definidos no namespace Config
    Wire.begin(Config::SDA_PIN, Config::SCL_PIN); // Inicializa a comunicação I2C
    Wire.setClock(400000); // Define a velocidade do I2C para 100 kHz
    pinMode(Config::LED_PIN, OUTPUT);
    pinMode(Config::BLE_LED_PIN, OUTPUT);
    if(!sensor.initialize()) {
        handleSensorError();
    }


    if (!FFat.begin(FORMAT_FFAT_IF_FAILED)) {
        Serial.println("FFat Mount Failed even after formatting!");
        return;
    }

    setupBLE(); // Inicializa o serviço BLE

    sensor.calibrateAccelGyro(); // Calibração do acelerômetro e giroscópio
    initializeFilters();
    last_update = millis();

    // Inicializa o sensor MAX17043
    //if (!lipo.begin()) {
    //    handleBatteryError();
    //}

    Serial.println("MAX17043 iniciado com sucesso.");
    //lipo.quickStart();
    Serial.println("Quick Start executado no MAX17043.");

    lastOtaNotification = 0;
    lastSensorNotification = 0;

    // Inicializa o cartão SD
    //setupSDCard();
}

// ******************* Loop principal ******************* //
void loop() {
    // Verifica o modo de operação atual
    switch (MODE) {
        case NORMAL_MODE:
            // Modo normal de operação - processamento de sensores e notificações BLE
            if (deviceConnected) {
                digitalWrite(Config::BLE_LED_PIN, HIGH);
                
                // Comandos do protocolo OTA 
                if (sendMode) {
                    uint8_t fMode[] = {0xAA, FASTMODE};
                    registerOtaNotification();
                    pCharacteristicTX->setValue(fMode, 2);
                    pCharacteristicTX->notify();
                    delay(50); // Delay importante para estabilidade do BLE
                    sendMode = false;
                }
        
                if (sendSize) {
                    unsigned long x = FLASH.totalBytes();
                    unsigned long y = FLASH.usedBytes();
                    uint8_t fSize[] = {0xEF, (uint8_t) (x >> 16), (uint8_t) (x >> 8), (uint8_t) x, 
                                      (uint8_t) (y >> 16), (uint8_t) (y >> 8), (uint8_t) y};
                    pCharacteristicTX->setValue(fSize, 7);
                    pCharacteristicTX->notify();
                    delay(50); // Delay importante para estabilidade do BLE
                    sendSize = false;
                }
                
                // Processamento dos sensores apenas se não estiver pausado para OTA
                if (!pauseNotifications) {
                    unsigned long current_time = millis();
    
                    // Verifica a bateria a cada intervalo definido
                    if (current_time - last_battery_check >= Config::battery_check_interval) {
                        last_battery_check = current_time;
    
                        // Código de leitura da bateria aqui...
                        // float carga = lipo.getSOC();
                        // float tensao = lipo.getVoltage();
                        
                        // Envio dos dados da bateria
                        // sendBatteryPercentage(carga);
                    }
    
                    // Atualiza os sensores a cada intervalo definido
                    if (current_time - last_sensor_update >= Config::sensor_update_interval) {
                        last_sensor_update = current_time;
    
                        if (sensor.update()) {
                            const unsigned long now = millis();
                            const float delta_time = (now - last_update) / 1000.0f;
                            last_update = now;
    
                            const auto data = sensor.getData();
    
                            const float pitch_acc = DataProcessor::calculateAccelerometerPitch(
                                data.accel.x, data.accel.y, data.accel.z);
    
                            const float roll_acc = DataProcessor::calculateAccelerometerRoll(
                                data.accel.y, data.accel.z);
    
                            // Filtra valores de pitch e roll com o Filtro de Kalman
                            const float filtered_pitch = pitch_filter.update(
                                pitch_acc, data.gyro.y, delta_time);
    
                            const float filtered_roll = roll_filter.update(
                                roll_acc, data.gyro.x, delta_time);
    
                            // Calcula a inclinação total do sensor
                            const float total_inclination = DataProcessor::calculateTotalInclination(
                                filtered_pitch, filtered_roll);
                            
                            // Envia dados via BLE com delays adequados entre notificações
                            Serial.print("Pitch: ");
                            Serial.println(filtered_pitch);
                            Serial.print(" Roll: ");
                            Serial.println(filtered_roll);
                            Serial.print(" Inclinação Total: ");
                            Serial.println(total_inclination);
                            sendAngleValue(filtered_roll);
                            sendPitchAndRoll(filtered_pitch - 6, filtered_roll);
                            //delay(10);
                            //sendPitchAndRoll(filtered_pitch, filtered_roll);
                        }
                    }
                }
            } else {
                digitalWrite(Config::BLE_LED_PIN, LOW);
                blinkBleLed();
            }
            break;
        
        case UPDATE_MODE:
            // Modo de recebimento do firmware - nesse modo não processa sensores
            if (request) {
                uint8_t rq[] = {0xF1, (uint8_t)((cur + 1) >> 8), (uint8_t)((cur + 1) & 0xFF)};
                pCharacteristicTX->setValue(rq, 3);
                pCharacteristicTX->notify();
                delay(50);  // Delay importante para estabilidade do BLE
                request = false;
            }
        
            if (cur + 1 == parts) { // received complete file
                uint8_t com[] = {0xF2, (uint8_t)((cur + 1) >> 8), (uint8_t)((cur + 1) & 0xFF)};
                pCharacteristicTX->setValue(com, 3);
                pCharacteristicTX->notify();
                delay(50);  // Delay importante para estabilidade do BLE
                MODE = OTA_MODE;
            }
        
            if (writeFile) {
                // Escreve os dados do firmware no arquivo
                if (!current) {
                    writeBinary(FLASH, "/update.bin", updater, writeLen);
                } else {
                    writeBinary(FLASH, "/update.bin", updater2, writeLen2);
                }
            }
            break;
        
        case OTA_MODE:
            // Modo de instalação do firmware
            if (writeFile) {
                // Finaliza a escrita do arquivo
                if (!current) {
                    writeBinary(FLASH, "/update.bin", updater, writeLen);
                } else {
                    writeBinary(FLASH, "/update.bin", updater2, writeLen2);
                }
            }
        
            // Verifica se o arquivo foi recebido completo
            if (rParts == tParts) {
                Serial.println("Firmware recebido completamente");
                delay(1000);
                updateFromFS(FLASH);  // Inicia a atualização
            } else {
                writeFile = true;
                Serial.println("Recebimento do firmware incompleto");
                Serial.print("Esperado: ");
                Serial.print(tParts);
                Serial.print(" Recebido: ");
                Serial.println(rParts);
                delay(2000);
                // Se o firmware estiver incompleto, volta ao modo normal
                MODE = NORMAL_MODE;
                pauseNotifications = false;
            }
            break;
    }
}

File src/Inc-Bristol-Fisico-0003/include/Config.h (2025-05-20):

#pragma once
#include <Arduino.h>

namespace Config {
    constexpr uint8_t MPU_I2C_ADDRESS = 0x68;
    constexpr uint8_t LED_PIN = 2;
    constexpr uint8_t BLE_LED_PIN = 32;
    constexpr uint8_t SD_CS_PIN = 21;
    constexpr uint8_t SD_MISO_PIN = 7;
    constexpr uint8_t SD_MOSI_PIN = 7;
    constexpr uint8_t SD_CLK_PIN = 15;
    constexpr uint8_t SDA_PIN = 21;
    constexpr uint8_t SCL_PIN = 22;
    constexpr unsigned long SERIAL_BAUD_RATE = 115200;
    constexpr int positive_offset_angle = 5;
    constexpr int negative_offset_angle = 8;
    constexpr int battery_check_interval = 1000;
    constexpr int sensor_update_interval = 0;
    constexpr char device_name[] = "Inclinômetro Bristol 0002";
    
    namespace Kalman {
        constexpr float PITCH_Q_ANGLE = 0.001f;
        constexpr float PITCH_Q_BIAS = 0.003f;
        constexpr float PITCH_R_MEASURE = 0.03f;
        
        constexpr float ROLL_Q_ANGLE = 0.001f;
        constexpr float ROLL_Q_BIAS = 0.003f;
        constexpr float ROLL_R_MEASURE = 0.03f;
    }
}

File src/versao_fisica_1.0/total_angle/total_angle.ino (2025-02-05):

// ******************* Imports e bibliotecas ******************* 
#include <Arduino.h>
#include <MPU9250.h>
#include <Wire.h>
#include <math.h>

// *********************** Configurações ***********************
namespace Config {
    // TODO: Adicionar lógica para verificar os dois endereços (0x68 e 069)
    // Caso não consiga encontrar o dispositivo em um, tenta no outro. Se não achar em nenhum dos dois... problema
    constexpr uint8_t MPU_I2C_ADDRESS = 0x68;
    constexpr uint8_t LED_PIN = 2;
    constexpr unsigned long SERIAL_BAUD_RATE = 115200;
    
    namespace Kalman {
        /*
        Q_Angle: 
        Controla o quanto o filtro "confia" na previsão do giroscópio
        Valores menores: o filtro confia mais no giroscópio
        Valores maiores: o filtro confia menos no giroscópio

        Q_Bias:
        Controla o quanto o filtro ajusta o "erro sistemático" do giroscópio
        Valores menores: o filtro ajusta menos o bias
        Valores maiores: o filtro ajusta mais o bias

        R_Measuse:
        Controla o quanto o filtro "confia" no acelerômetro
        Valores menores: o filtro confia mais no acelerômetro
        Valores maiores: o filtro confia menos no acelerômetro
        */
        constexpr float PITCH_Q_ANGLE = 0.001f;
        constexpr float PITCH_Q_BIAS = 0.003f;
        constexpr float PITCH_R_MEASURE = 0.03f;
        
        // Separa se o PITCH (inclinação frontal, frente/trás) e o ROLL (Inclinação lateral, para os lados) porque eles podem possuir comportamentos diferentes

        constexpr float ROLL_Q_ANGLE = 0.001f;
        constexpr float ROLL_Q_BIAS = 0.003f;
        constexpr float ROLL_R_MEASURE = 0.03f;
    }
}

// *********************** KalmanFilter ***********************
// O Filtro de Kalman é um algoritmo matemático usado para estimar o estado de um sistema a partir de medições ruidosas
// Aqui, o Filtro de Kalman é utilizado para realizar a fusão entre os dados do acelerômetro e do giroscópio a fim de obter o ângulo 
// total do dispositivo. O filtro nos ajuda a diminuir ruidos e erros provenientes de vibrações
class KalmanFilter {
public:
    // Construtor
    KalmanFilter(float q_angle, float q_bias, float r_measure)
        : Q_angle(q_angle), Q_bias(q_bias), R_measure(r_measure) {} // Definidos em Config::Kalman::PITCH_Q_ANGLE...

    // Configura o estado inicial do filtro
    void initialize(float initial_angle) {
        angle = initial_angle;
        bias = 0.0f;
        P[0][0] = P[0][1] = P[1][0] = P[1][1] = 0.0f; // Zera tudo para a primeira medição
    }

    // Atualiza o filtro com uma nova medição, mantendo uma malha fechada com feedback vindos dos sensores e possibilitando um cálculo sempre atualizado
    float update(float measurement, float rate, float delta_time) { // measurement: accel; rate: gyro; delta_time: tempo desde ultima medição
        /* As etapas seguem como:
        1. Predição: Atualiza o estado e a matriz de covariância com base no giroscópio
        2. Cálculo do Ganho de Kalman: Determina o peso da medição e da previsão
        3. Correção: Ajusta o estado com base na medição
        4. Atualização da Matriz de Covariância: Atualiza a incerteza da estimativa
        */ 
        predict(rate, delta_time);
        calculateKalmanGain();
        correct(measurement);
        updateCovarianceMatrix();
        return angle; // Angulo final estimado após a atualização
    }

private:
    const float Q_angle, Q_bias, R_measure;
    float angle = 0.0f; 
    float bias = 0.0f; 
    float P[2][2] = {{0.0f, 0.0f}, {0.0f, 0.0f}}; // Matriz de covariância do erro

    // Atualiza o estado e a matriz de covariância com base no giroscópio
    void predict(float rate, float delta_time) {
        // Angulo integra a taxa angular do giroscópio, já corrigida pelo bias
        angle += delta_time * (rate - bias);

        // Matriz de covariância atualiza a incerteza da estimativa
        P[0][0] += delta_time * (delta_time * P[1][1] - P[0][1] - P[1][0] + Q_angle);
        P[0][1] -= delta_time * P[1][1];
        P[1][0] -= delta_time * P[1][1];
        P[1][1] += Q_bias * delta_time;
    }

    void calculateKalmanGain() {
        const float S = P[0][0] + R_measure;
        K[0] = P[0][0] / S;
        K[1] = P[1][0] / S;
    }

    void correct(float measurement) {
        const float innovation = measurement - angle;
        angle += K[0] * innovation;
        bias += K[1] * innovation;
    }

    void updateCovarianceMatrix() {
        const float P00_temp = P[0][0];
        const float P01_temp = P[0][1];
        
        P[0][0] -= K[0] * P00_temp;
        P[0][1] -= K[0] * P01_temp;
        P[1][0] -= K[1] * P00_temp;
        P[1][1] -= K[1] * P01_temp;
    }

    float K[2] = {0.0f, 0.0f};
};

// *********************** SensorManager ***********************
// Feita para inicializar sensor, calibrar, atualizar dados e fornecer dados em estrutura adequada
class SensorManager {
public:
    // Construtor
    SensorManager(MPU9250& sensor, MPU9250Setting& settings, TwoWire& wire) // Referencia ao objeto do sensor MPU9250, settings do sensor e interface I2C
        : mpu(sensor), settings(settings), wire(wire) {}                    // Utilizei referências para evitar cópias desnecessárias de objetos

    // Inicializar sensor (endereço I2C padrão é 0x68, mas pode ser alterado na placa do sensor)
    bool initialize() {
        wire.begin();
        return mpu.setup(Config::MPU_I2C_ADDRESS, settings, wire); // Retorno: true se o sensor foi inicializado com sucesso, false caso contrário
    }

    // calibração do acelerômetro e do giroscópio
    // Remove erros sistemáticos (bias) do sensor
    void calibrateAccelGyro() {
        Serial.println("Calibrando acelerômetro e giroscópio...");
        mpu.calibrateAccelGyro();
    }

    bool update() { return mpu.update(); }

    /* Define uma estrutura para armazenar os dados do sensor de forma organizada

    accel: Dados do acelerômetro (aceleração nos eixos X, Y, Z).
    gyro: Dados do giroscópio (velocidade angular nos eixos X, Y, Z).
    mag: Dados do magnetômetro (campo magnético nos eixos X, Y, Z).
    yaw, pitch, roll: Ângulos de orientação calculados pelo sensor.

    */
    struct SensorData {
        struct { float x, y, z; } accel, gyro, mag;
        float yaw, pitch, roll;
    };

    SensorData getData() const {
        return { // Retorno: Um objeto SensorData contendo todos os dados do sensor
            {mpu.getAccX(), mpu.getAccY(), mpu.getAccZ()},
            {mpu.getGyroX(), mpu.getGyroY(), mpu.getGyroZ()},
            {mpu.getMagX(), mpu.getMagY(), mpu.getMagZ()},
            mpu.getYaw(), mpu.getPitch(), mpu.getRoll()
        };
    }

private:
    MPU9250& mpu;
    MPU9250Setting& settings;
    TwoWire& wire;
};
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

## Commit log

2025-01-22 chore: adiciona estrutura de pastas inicial do projeto
2025-01-23 docs: adiciona secao de storyboard na documentacao
2025-01-26 docs: adiciona casos de teste da simulacao
2025-02-05 feat: adiciona versao inicial de código modularizado do dispositivo fisico
2025-02-06 feat: adiciona envio de dados via BLE BLE: Bluetooth Low Energy
2025-02-10 feat: adiciona envio de angulo em demais eixos via bluetooth
2025-02-17 feat: adiciona arquivos de placa de circuito impressa
    [PCI_INICIAL_1.0.csv, PCI_INICIAL_1.0.kicad_pcb, PCI_INICIAL_1.0.kicad_sch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]
2025-02-17 docs: adiciona documentacao de primeiro mes
2025-02-21 feat: adiciona arquivos 2.0 de PCI
    [PCI_INICIAL_2.0.kicad_pcb]
2025-02-21 docs: adiciona documentacao final de primeiro mes
2025-03-21 feat: corrige erros do leitor de bateria e adiciona led ble
    [BluetoothLowEnergy.cpp, BluetoothLowEnergy.h, Config.h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]
2025-03-21 fix: corrige declaracao de string
    [Config.h]
2025-03-23 fix: corrige erros de envio de dados e nome do dispositivo
    [Config.h]
2025-03-23 feat: adiciona armazenamento de dados no cartão sd
2025-03-24 docs: adiciona documentação de final de 2o mes
2025-03-29 feat: adiciona libs kicad
    [PCI_INICIAL_1.0.csv]
2025-04-22 feat: adiciona modificacoes para esp32 s3
2025-05-03 feat/docs: adiciona documentacao 3o mes e PCI Industrial
    [PCI_COMPLETA_1.0.csv, PCI_COMPLETA_1.0.kicad_pcb, PCI_COMPLETA_1.0.kicad_sch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]
2025-06-15 fix: corrige envio de valores de angulo
    [PCI_COMPLETA_1.0.kicad_pcb, PCI_COMPLETA_1.0.kicad_sch]
